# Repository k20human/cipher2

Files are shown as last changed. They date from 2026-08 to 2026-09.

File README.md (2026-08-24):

# cyberdeck

A handheld cyberdeck built around an Android phone: a lit pushbutton wakes its
screen, a rotary encoder sets the volume, a trackball moves a cursor, and the
phone's home screen is replaced by **CIPHER-2**, a landscape HUD served by the
phone to itself.

Three subsystems, each in its own directory, each with its own README.

```
                    USB HID (Power, volume, mute, mouse)
        ┌──────────────────────────────────────────────────┐
        │                                                  ▼
  ┌───────────┐                                    ┌───────────────┐
  │  Arduino  │                                    │    Android    │
  │  32U4     │◄───────────────────────────────────│    phone      │
  └───────────┘   USB serial "S<0|1> B<0..100>"    └───────────────┘
     button                (screen, battery)          │         ▲
     encoder                                          │ HTTP    │
     trackball                                        ▼ on 127.0.0.1
     button LED                                    ┌───────────────┐
                                                   │  CIPHER-2 PWA │
                                                   │  + Python API │
                                                   └───────────────┘
```

The board and the phone talk over one USB cable, in both directions at once but
for unrelated purposes:

- **Board → phone**, as a USB HID device: the Power key wakes and sleeps the
  screen, the volume and mute keys follow the encoder, and mouse reports follow
  the trackball. To the phone this is indistinguishable from its own buttons.
- **Phone → board**, as a USB serial device: the companion app reports screen
  state and battery level, one line every 5 seconds, so the button's LED can
  show them. Silence is information too — 15 s without a line and the LED starts
  blinking.

The interface never touches the network. Both the file server and the status
API listen on `127.0.0.1` only, and the page holds no language model and makes
no outbound request.

## Subsystems

| Directory | What it is | Read |
|---|---|---|
| `arduino/` | The `screen_wake` sketch: wake button, EC11 encoder, PIM447 trackball, button LED driven by what the phone reports. Host-side test suites in `arduino/test/`. | [arduino/README.md](arduino/README.md) |
| `android/` | `cyberdeck-reporter`, the companion app: watches the screen and the battery, writes them to the serial port, restarts at boot. | [android/README.md](android/README.md) |
| `gui/` | `CIPHER-2`, the deck's home screen: a PWA served from the phone by a small Python server that also exposes `GET /api/status`. | [gui/README.md](gui/README.md) |
| `pcb/` | `cipher2-panel`, the hub board: a Pro Micro on sockets, four connectors, and the cables to the controls. Generated from a netlist, not drawn. | [pcb/README.md](pcb/README.md) |

## Hardware

Developed and tested on an Arduino Leonardo driving an Android phone over USB
OTG. The board must have native USB — an Uno or a Nano cannot work — and the
alternatives are listed in [arduino/README.md](arduino/README.md#boards). The
phone side needs Termux and Termux:API, both from F-Droid.

The controls started out on flying wires and now have a board of their own:
`pcb/` holds a 100 × 42 mm two-layer hub that takes the Pro Micro on sockets
and gives the button, the encoder and the trackball a connector each — they
are mounted in the enclosure and reach it on cable. It is generated from a
netlist rather than drawn, and a test reads `screen_wake.ino` itself to check
the two agree — see [pcb/README.md](pcb/README.md).

## Quick start

Each subsystem stands on its own; none of them needs the other two to be
verified.

```sh
# Arduino — host test suites, no board required
make -C arduino/test test

# Arduino — build and upload
arduino-cli compile --fqbn arduino:avr:leonardo arduino/screen_wake
arduino-cli upload  --fqbn arduino:avr:leonardo -p /dev/ttyACM0 arduino/screen_wake

# GUI — test suite, no phone required (needs node and python3)
node --test "gui/test/**/*.js"

# GUI — serve locally
gui/serve.sh

# Android — unit tests (needs JDK 21 and the Android SDK)
cd android && ./gradlew test

# PCB — tests, then the fabrication package (needs KiCad 9)
make -C pcb test
make -C pcb fab
```

The Arduino sketch can be exercised without the phone: `arduino/tools/inject.py`
replays exactly the lines the Android app would send, including the silence that
puts the LED into its fault blink.

## Licence

MIT — see [LICENSE](LICENSE).

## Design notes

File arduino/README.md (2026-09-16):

# screen_wake

An illuminated pushbutton that turns an Android phone's screen on (and off), a
rotary encoder that sets its volume, and a trackball that moves a cursor on it.

The Arduino announces itself to the phone as a USB HID device. On the *consumer
control* interface it sends the Power, Volume +/- and Mute keys, which Android
translates into `KEY_POWER`, `KEY_VOLUMEUP`, `KEY_VOLUMEDOWN` and `KEY_MUTE`:
the effect is identical to that of the phone's own physical buttons. As a mouse,
it moves the pointer and clicks.

## Hardware

| Part | Detail |
|---|---|
| Board | ATmega32U4 — see *Boards* below |
| Button | Momentary pushbutton with a built-in LED, 4 wires, 3-6 V LED |
| Encoder | Bare EC11 — 3 pins for the quadrature, 2 for the switch |
| Trackball | Pimoroni PIM447 — I²C, with click and RGBW LED on the bus |
| Link | Android phone → OTG → unpowered USB hub → Arduino |

### Boards

Developed and tested on an **Arduino Leonardo** (`2341:8036`).

The board must have **native USB**, and the sketch's HID library (`HID-Project`
by NicoHood) targets AVR. That leaves the ATmega32U4 family, all
interchangeable here:

| Board | Note |
|---|---|
| Arduino Leonardo | The reference for this project |
| Arduino Micro | Same chip, smaller footprint |
| Pro Micro and clones | Cheapest option; check the 5 V variant, not the 3.3 V/8 MHz one |
| Adafruit ItsyBitsy 32u4, LilyPad USB | Same chip, different form factors |

An **Uno or a Nano cannot work**, whatever the wiring: their USB goes through a
CH340 or FT232 serial bridge, so they are physically unable to present
themselves as a keyboard. No sketch can work around that.

Native-USB boards that are *not* AVR — SAMD (Zero, MKR), RP2040, ESP32-S2 — do
have the USB capability but not `HID-Project`. Moving to one is a port of the
HID layer, not a change of `--fqbn`.

## Wiring

| Pin | Use |
|---|---|
| **D2** | Trackball — SDA, I²C bus |
| **D3** | Trackball — SCL, I²C bus |
| **D4** | Encoder switch (mute) |
| **D5** | Wake button |
| **D7** | Encoder, signal A |
| **D8** | Encoder, signal B |
| **D9** | Button LED, through a **150 Ω** resistor |

Every return goes to **GND**: the button's second contact, the LED cathode, the
encoder's middle pin, its switch's second contact, the trackball's ground. The
trackball also takes **5 V**.

**D2 and D3 are the ATmega32U4's only hardware I²C lines.** The trackball module
occupies them, and exposes its click *and* its four LEDs there — two pins for
both functions. That, and only that, is why the wake button moved from D2 to D5.

D7 and D8 for the encoder are not arbitrary either: once D2 and D3 are taken,
they are the last two pins able to raise an interrupt — D7 through an external
interrupt, D8 through a pin-change interrupt. The firmware polls the pins in a
loop rather than using interrupts; should detents ever be missed, the switch
could be made without touching a single wire.

No input needs a resistor: `INPUT_PULLUP` enables the microcontroller's internal
pull-up, which holds the pin at 5 V when idle. Acting on the control ties the
pin to ground, and the firmware detects that fall to 0 V.

### EC11 rotary encoder

Three pins on one side — the quadrature — and two on the other — the switch. The
**middle** one of the three is the common.

| Pin | To |
|---|---|
| 3-pin side, outer | **D7** |
| 3-pin side, **middle** | **GND** |
| 3-pin side, other outer | **D8** |
| 2-pin side, either | **D4** |
| 2-pin side, the other | **GND** |

**If the rotation comes out backwards**, swap the D7 and D8 wires. That is the
encoder's only wiring hazard, and it is harmless.

The 150 Ω resistor is a safety net. An LED sold as "3-6 V" almost always carries
its own, but in the worst case (no internal resistor, a red LED at 2 V) it caps
the current at 20 mA — the recommended limit for an ATmega32U4 pin.

### Pimoroni PIM447 trackball

An I²C module: the ball moves a cursor on the phone, its contact gives both
mouse buttons, and its RGBW LED shows the battery level.

**The module has a single contact**, and three gestures depend on it.
**Movement** is what tells them apart.

| What you do | What happens |
|---|---|
| You move the ball before `RIGHT_CLICK_MS` | The left button goes down → **drag**, until release |
| You do not move until the threshold | **Right click**, sent at once, finger still down |
| You release before the threshold without moving | **Left click** |

The left click can only fire on release: as long as the finger is down and the
threshold is not reached, nothing distinguishes a short press from a long press
in progress. The right click, on the other hand, fires **as the threshold is
crossed**, the way a touch interface behaves.

**You have to start moving within the delay** to get a drag. Press, wait, then
move gives a right click followed by an ordinary pointer move. That is the price
of fitting three gestures onto one contact.

`DRAG_THRESHOLD` sets the distance to travel before a hold becomes a drag. A
ball is sensitive and a resting finger nudges it: too low, and your right clicks
turn into accidental drags.

| Module pin | To |
|---|---|
| SDA | **D2** |
| SCL | **D3** |
| 5V (or 3V3) | **5V** |
| GND | **GND** |

The module is rated for 3.3 V **and** 5 V: it connects straight to the board, no
level shifter. An onboard microcontroller reads the click and drives the four
LEDs, exposing everything on the bus — **so the trackball costs no pin beyond
the two of the I²C bus**.

The bus runs at 100 kHz, `Wire`'s default. Do not speed it up: the manufacturer
rates the module at 250 kHz maximum.

**The module's orientation is baked into `decodeFrame`.** It sits a quarter turn
round in this deck — its own "right" points at the bottom of the panel — so the
axes are swapped once, where the module's language stops and the pointer's
begins. Mount yours differently and the pointer will travel at an angle to the
ball; the fix is those two lines in `trackball.h` and nothing else. The symptom
is unmistakable: push the ball up and the cursor goes sideways.

**What its LED says**

| State | Colour |
|---|---|
| Battery ≥ `BATT_GREEN_PCT` | green |
| Between the two thresholds | amber, by linear fade |
| Battery ≤ `BATT_RED_PCT` | red |
| Screen off | same hue, heavily dimmed |
| App silent **or** USB link down | **off** |

Going dark wins over dimming. When the app falls silent, the percentage the
board holds is minutes old: this build never asserts what it can no longer
answer for, and the same rule silences the button LED's battery alert.

**Without the module**, the identification probe fails at startup and the
trackball is never polled. Everything else — button, encoder, LED, serial link —
works exactly the same. That absence is a test case in its own right, not a
degraded mode.

**`POINTER_GAIN` is the one setting to make on the bench.** It multiplies the
ball's raw displacement. Too low and the cursor crawls; too high and it jumps.
The displacement is clamped to ±127 per report regardless, a bound imposed by
the mouse API.

### Identifying the button's 4 wires with a multimeter

Multimeter on **continuity** (the 🔊 symbol, which makes the meter beep when the
two probes are electrically joined):

1. Test the wires pair by pair **without pressing** the button. None should
   beep.
2. Press the button and test again. The pair that beeps is the **contact**.
   Those two wires go to D5 and GND, either way round.
3. The two remaining wires are the **LED**. Switch the meter to **diode** mode
   (the ▷| symbol) and test them both ways: the direction in which the LED glows
   faintly gives the polarity. The red probe is then on the anode (+, to D9), the
   black one on the cathode (−, to GND).

If step 3 gives nothing, the meter's test voltage is too low for the LED. Power
it carefully instead through a 330 Ω resistor from the board's 5 V, trying both
directions: at that value there is no risk.

## Building and uploading

```sh
arduino-cli compile --fqbn arduino:avr:leonardo screen_wake
arduino-cli upload  --fqbn arduino:avr:leonardo -p /dev/ttyACM0 screen_wake
```

`/dev/ttyACM0` belongs to the `dialout` group. To upload without `sudo`:

```sh
sudo usermod -aG dialout $USER    # then log out and back in
```

Dependencies: the `arduino:avr` core and the `HID-Project` library (NicoHood).

### If the upload fails

```
Error: butterfly_recv(pgm, &c, 1) failed
Error: initialization failed  (rc = -1)
```

An **intermittent** failure, seen once and gone on the second attempt with no
change at all. Re-running the command is usually enough.

The mechanism: to upload, `arduino-cli` opens the port at 1200 baud, which
restarts the board into its Caterina bootloader. That bootloader re-enumerates
as `idProduct=0036` and waits only **8 seconds** before handing back to the
sketch. The error above means avrdude opened the port but received nothing
during that window.

Prime suspect, unconfirmed: ModemManager is running and udev marks the port
`ID_MM_CANDIDATE=1`. Every time the bootloader appears, ModemManager may open it
to send AT commands, which garbles the AVR109 protocol. It is a race, hence the
intermittence. To rule it out for good:

```sh
sudo tee /etc/udev/rules.d/99-arduino-no-modemmanager.rules >/dev/null <<'EOF'
SUBSYSTEM=="usb", ATTR{idVendor}=="2341", ENV{ID_MM_DEVICE_IGNORE}="1"
EOF
sudo udevadm control --reload-rules
```

To watch the sequence live (membership of `adm` is enough, root is not needed):

```sh
journalctl -k --since "5 min ago" | grep -iE "usb|cdc_acm"
```

### Checking that the firmware is running

Without pressing anything, you can confirm the board really exposes the Power
key. The kernel parses the HID descriptor and publishes the codes the device
declares it can emit:

```sh
grep -A6 "Arduino" /proc/bus/input/devices
```

The current firmware exposes **two** devices: a generic entry — the Power,
volume and mute keys — and a `Mouse` entry, added for the trackball.

**The distinguishing criterion changed when the trackball arrived.** Seeing
`Mouse` no longer signals anything wrong: it is now expected. Seeing `Keyboard`
**as well**, on the other hand, betrays the stock factory firmware, which
exposed mouse *and* keyboard while never exposing a single media key. So the
call goes:

| What you see | What is running |
|---|---|
| A generic entry **and** `Mouse` | the current firmware |
| `Mouse` **and** `Keyboard` | the stock factory firmware — the upload did not take |
| A generic entry alone | a firmware predating the trackball |

The check that depends on none of these subtleties remains the best one: the
kernel publishes the codes the device declares it can emit, and `KEY_POWER`
(code 116) must be among them.

## What the LED says

Since the sketch reads the lines sent by the Android app (`led_state.h`,
function `ledLevel()`), the LED no longer reflects the state of the USB bus but
what the app reports. The order below is a priority order, not a list of
independent states: each row masks all the ones that follow.

| Priority | Condition | LED | What it means |
|---|---|---|---|
| 1 | Button or wheel press | Off, 120 ms | The key has just gone out (confirmation) |
| 2 | USB link absent | Off | OTG has dropped, or the rig has lost power |
| 3 | Android app silent | Blinks at 4 Hz | No line received for 15 s, or ever |
| 4 | Low battery reported | Two sharp flashes, every 5 s | Below 15 %, until back above 20 % (hysteresis) |
| 5a | Screen reported on | Steady glow | — |
| 5b | Screen reported off | Slow breathing, ~4 s | — |

The breathing does not peak exactly at the steady glow's level: integer
truncation of the squared triangular ramp (`breatheLevel()` in `led_state.h`)
caps the real peak at 23 when `LED_AWAKE`/`BREATHE_CEIL` are 24 — one PWM step,
invisible to the eye, and never more than that. The more active the screen, the
brighter and steadier the light.

The battery alert (priority 4) overlays state 5 but never a higher state: it
stays silent while the app is silent (priority 3), because a reading that can no
longer be guaranteed fresh must assert nothing about the battery.

Press confirmation is a **blackout** rather than a flash, because a dark gap is
noticeable from any state — including at the top of the breathing cycle or
mid-battery-flash, where a flash would go unnoticed.

Both buttons trigger it — the wake button and the wheel's click — because it
means "a key has just gone out", not "the screen has toggled". **Volume steps
are excluded**: a fast rotation would strobe the LED, and the confirmation would
become background noise rather than a signal.

### The board's TX/RX LEDs are off on purpose

Not through a fault. The Arduino core blinks them on every USB packet; with the
app reporting several times a second, that gives a permanent flicker nobody
reads. `silenceUsbLeds()` switches both pins back to inputs at startup, which
cuts the current through the LEDs without touching anything else.

It is the **direction register** that is changed, not the output: the core keeps
writing the port bits from its USB interrupt, and a pin set as an input ignores
them. It arms them as outputs only once, in `USBDevice.attach()`, which runs
before `setup()` — hence the window to undo its work.

Removing the call in `setup()` is enough to get them back. The board's "L" LED
(pin 13) is not affected.

### Where this information comes from

No longer the USB bus. This section used to describe a correlation between the
bus's suspend state (`USBDevice.isSuspended()`) and the phone's screen —
approximate and not guaranteed. The source is now explicit: the Android app
(`ReporterService`) watches the screen itself (`ACTION_SCREEN_ON` /
`ACTION_SCREEN_OFF` broadcasts) and the battery (`BatteryManager`), and reports
the real state line by line over that same serial port, every 5 s or immediately
on each screen toggle. The line format, the exact cadence and the reasoning
behind each choice are documented in `android/README.md` rather than duplicated
here.

The three functions below are still used in `screen_wake.ino`, but for a
narrower role than before: none of them serves to guess the screen state any
more, since the app now states it explicitly.

| Function | Current role |
|---|---|
| `USBDevice.configured()` | Feeds priority 2 of the table above (USB link present or not); also guards the keep-alive |
| `USBDevice.isSuspended()` | Decides whether `togglePhoneScreen()` must wake the bus before sending the key; same guard as above in the keep-alive |
| `USBDevice.wakeupHost()` | Wakes the bus, called only from `togglePhoneScreen()` |

`wakeupHost()` is only ever called on a real press, never automatically:
triggering it from the keep-alive would wake the phone every five minutes, night
included.

## Tuning points

Three files share the settings: the LED's vocabulary is in
`screen_wake/led_state.h`, the behaviour of the physical inputs in
`screen_wake/controls.h`, and the link's own timings at the top of
`screen_wake/screen_wake.ino`.

In `led_state.h`:

| Constant | Role |
|---|---|
| `LED_AWAKE` | Steady-glow intensity, 0-255. Also caps the breathing and serves as the blink's high level |
| `BREATHE_FLOOR` | Darkest point of the breathing cycle |
| `BREATHE_CEIL` | Nominal breathing ceiling, an alias of `LED_AWAKE` — never reached exactly (see above) |
| `BREATHE_MS` | Duration of one full breathing cycle |
| `BLINK_MS` | Half-period of the 4 Hz blink (app silent) |
| `BLACKOUT_MS` | Duration of the confirmation blackout |
| `APP_TIMEOUT_MS` | Time without a received line before declaring the app silent |
| `BATT_LOW_PCT` / `BATT_CLEAR_PCT` | Low/high thresholds of the battery hysteresis |
| `BATT_PERIOD_MS` | Period of the battery alert's two flashes |
| `BATT_FLASH_LEVEL` / `BATT_FLASH_MS` / `BATT_FLASH_GAP_MS` | Intensity, duration and spacing of each flash |
| `RX_BUF` | Maximum length of a serial line; beyond it, the line is truncated and rejected |

In `controls.h`:

| Constant | Role |
|---|---|
| `DEBOUNCE_MS` | Debounce, shared by both buttons; raise it if one press fires twice |
| `STEPS_PER_DETENT` | Quadrature transitions per detent. **If one detent changes the volume by two steps, set 2 instead of 4** |

In `trackball.h`:

| Constant | Role |
|---|---|
| `POINTER_GAIN` | Multiplier on the ball's displacement. **The only setting that needs the module in hand** |
| `RIGHT_CLICK_MS` | Press duration beyond which the click becomes a right click. Raise it if a hesitant press fires one unintentionally |
| `DRAG_THRESHOLD` | Distance to travel, in raw steps summed over both axes, for a hold to become a drag. Raise it if a resting finger starts accidental drags |
| `POINTER_MAX` | `127`, the bound imposed by `Mouse.move`; do not raise |
| `LED_FULL` | RGBW intensity with the screen on, capped low out of power caution |
| `LED_DIMMED` | RGBW intensity with the screen off |
| `BATT_GREEN_PCT` / `BATT_RED_PCT` | Bounds of the green → red gradient |

In `screen_wake.ino`:

| Constant | Role |
|---|---|
| `KEY_HOLD_MS` | Simulated press duration; stay below 500 ms |
| `RESUME_MS` | Delay after `USBDevice.wakeupHost()` before sending the key, time for the bus to settle |
| `KEEPALIVE_MS` | Interval of the empty HID report (see below) |

`STEPS_PER_DETENT` is the rig's one hardware unknown. Most EC11s emit four
transitions between two detents, some emit two. One turn of the wheel on the
bench settles it in ten seconds.

Volume steps deliberately escape `KEY_HOLD_MS`: holding each key for 60 ms would
cap a rotation at sixteen steps per second, and the firmware would spend that
time in `delay()` missing encoder transitions.

The whole breathing range fits in 22 PWM steps between `BREATHE_FLOOR` and
`LED_AWAKE`. If it looks jerky at the bottom, raise `LED_AWAKE` to give it more
amplitude — at the cost of power draw.

## Checking from a host machine, without the phone

Two tools exercise the firmware without unrolling the whole hardware protocol.

### Host tests: `make -C test test`

```sh
make -C test test
```

Compiles and runs **two** suites with `g++` (`-std=c++17 -Wall -Wextra
-Werror`, see `test/Makefile`), which share the `test/check.h` assertion
harness:

| Suite | Covers |
|---|---|
| `test_led_state.cpp` ← `led_state.h` | LED priorities, battery hysteresis, serial line format |
| `test_controls.cpp` ← `controls.h` | quadrature decoding, detent counting, debounce of both buttons |

Neither touches hardware: pin mapping, PWM, USB enumeration and HID behaviour
can only be verified with the board in hand.

The controls suite was validated by mutation: altering any one of the sixteen
entries in the quadrature table, the detent divider or the debounce window makes
at least one assertion fail. A test that passes just as well with the code as
without it proves nothing, and that table is exactly the kind of place where you
notice too late.

### Replaying the app's lines: `tools/inject.py`

```sh
tools/inject.py 1 87        # one line, screen on, battery 87 %
tools/inject.py --hold 0 14 # the same line every 5 s, until Ctrl-C
tools/inject.py --silent    # opens the port and says nothing
```

Sends to `/dev/ttyACM0` (`--port` to change) exactly the lines `ReporterService`
would send — see `android/README.md` for the real format and cadence — with no
need for the phone or the app. `--silent` reproduces an app killed by the OEM's
power manager: the LED must start blinking at 4 Hz after 15 s, as in the table
above. Requires `pyserial` (`pip install pyserial`) and access to the port (see
the `dialout` note above).

## Known limitations

**Some OEM skins drop OTG after ~10 minutes of inactivity** — measured on MIUI.
The sketch sends an all-zero HID report every 5 minutes: real USB traffic, no
key pressed. How well that counter-measure holds up has not been validated in
the field. If the link drops anyway, look for an OTG option in the phone's
settings, or go back to a powered hub.

**Do not test the button while the Arduino is plugged into a computer.** Once
the sketch is uploaded, the board is an HID device to *any* host: a press will
send the Power key to the computer and put it to sleep or shut it down. Unplug
from the computer before wiring the button.

## If the phone ignores the key

Two fallbacks, to try in this order if `Consumer.press(CONSUMER_POWER)` is not
enough:

1. `System.write(SYSTEM_WAKE_UP)` — HID *Generic Desktop* usage 0x83,
   translated into `KEY_WAKEUP`. Turns the screen on but never off. Needs
   `System.begin()` in `setup()`.
2. `SingleConsumer` instead of `Consumer` — same key, but exposed on a dedicated
   HID interface rather than inside the composite descriptor. Some hosts cope
   better with it.

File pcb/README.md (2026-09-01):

# cipher2-panel

La carte de raccordement du deck : elle porte le Pro Micro sur embases, les
quatre connecteurs des commandes, et rien d'autre.

**100 × 42 mm**, deux couches, 1,6 mm, cuivre 35 µm. Elle se loge dans la bande
libre du boîtier, sous le hub USB, et n'est jamais visible.

## Ce que la carte n'est pas

Elle a d'abord été conçue comme une **façade** portant le bouton, l'encodeur et
le trackball soudés dessus. Le boîtier a tranché autrement : les trois commandes
sont montées dans le plastique, loin les unes des autres, et rejoignent la carte
par câble.

Ce qui reste est un concentrateur. Le circuit occupe un quart de la surface ; le
reste appartient au wordmark.

## La carte est générée, pas dessinée

Un seul fichier, `tools/netlist.py`, énumère les liaisons. Le schéma et la
carte en sont produits par script. Deux générateurs ne peuvent pas diverger
d'une source unique.

**Conséquence pratique : on ne modifie jamais `cipher2-panel.kicad_pcb`.** On
modifie `netlist.py` pour une liaison, `PLACEMENT` pour une position, `ROUTES`
ou `ESCAPES` pour une piste, puis on régénère. Une retouche faite dans
l'interface graphique est perdue à la prochaine exécution, sans avertissement.

```sh
make -C pcb test        # les 58 tests, sans matériel ni KiCad ouvert
make -C pcb board       # schéma + carte + DRC
make -C pcb fab         # tout cela, puis les fichiers de fabrication
make -C pcb render      # vues 3D et couches, dans render/
```

## Brochage

Contractuel : le firmware ne change pas pour s'adapter à la carte.

| Broche | Rôle | Sur la carte |
|---|---|---|
| **D2** | Trackball — SDA | `J1.2` |
| **D3** | Trackball — SCL | `J1.3` |
| **D4** | Contact de l'encodeur | `J3.4` |
| **D5** | Bouton d'éveil | `J4.1` |
| **D7** | Encodeur, voie A | `J3.1` |
| **D8** | Encodeur, voie B | `J3.3` |
| **D9** | LED du bouton, via R1 | `R1` → `J4.3` |

`test/test_pinout.py` lit `arduino/screen_wake/screen_wake.ino` lui-même et
vérifie cette correspondance. Une broche renumérotée dans le croquis fait
échouer les tests au lieu d'arriver sous forme de carte morte.

## Les quatre connecteurs

Toutes les broches sont sérigraphiées sur la carte. Les câbles sont des
liaisons Dupont femelle-femelle, **sans détrompeur** : rien n'empêche une
inversion, et sur le trackball une inversion met 5 V sur la masse du module.
C'est la sérigraphie, et elle seule, qui vous protège.

### `J1` — trackball, 5 points

`+5V · SDA · SCL · INT · GND`, dans l'ordre du connecteur du PIM447. Câble
droit, broche 1 sur broche 1.

**Garder ce câble sous 30 cm.** Le bus I²C tolère mal la capacité, et c'est la
raison pour laquelle la carte est calée à gauche du boîtier, près du trackball,
plutôt qu'à droite près du hub. L'USB, lui, tolère cinq mètres.

### `J3` — encodeur, 5 points

`A · GND · B · SW · GND`. L'EC11 a cinq bornes en deux groupes :

| Broche de la carte | Borne de l'encodeur |
|---|---|
| `A` | une extérieure du groupe de trois |
| `GND` | **celle du milieu du groupe de trois** |
| `B` | l'autre extérieure |
| `SW` | une des deux du groupe de deux |
| `GND` | l'autre |

Les noms de la fiche technique sont `A`, `C`, `B`, `S1`, `S2` ; la carte
affiche ce que chaque broche *est*, parce qu'on la câble un sachet de fils à
la main et pas la fiche technique sous les yeux.

**Une seule chose doit être juste : le milieu du groupe de trois va sur
`GND`.** A et B sont interchangeables — les inverser retourne le sens de
rotation, ce qui se corrige en échangeant deux fils. S1 et S2 n'ont pas de sens.

### `J4` — bouton d'éveil, 4 points

`SW · GND · LED+ · GND`. Le contact n'a pas de polarité ; la LED en a une, et
c'est le seul piège de ce connecteur.

### `J2` — broches libres, 6 points

`D1 · D0 · D6 · D10 · +5V · GND`. D0 et D1 sont la liaison série matérielle,
celle qu'on utilise pour déboguer. Les deux rails permettent de mesurer sans
démonter le module.

Il n'y a **pas de broche de reset** : la carte vit dans un boîtier fermé, et
débrancher l'USB fait le même travail depuis l'extérieur.

## Le Pro Micro est monté à l'envers

Ses barrettes ont été soudées broches vers le haut. Pour l'enficher dans les
embases, il faut le retourner — composants vers la carte — et cela échange ses
deux rangées de broches. **L'empreinte les rééchange**, ce qui rend le montage
correct sans dessouder 24 broches.

Le coût est permanent et il faut le connaître : **un Pro Micro de remplacement
soudé de la façon habituelle ne rentrera pas.** Il faudra soit refaire ses
barrettes broches vers le bas, soit inverser l'empreinte dans
`tools/build_footprints.py`.

La sérigraphie porte `PRO MICRO - COMPONENTS DOWN`. Monté à l'endroit, le
module met **5 V sur la masse du trackball** et le détruit.

**Les embases et les barrettes ne figurent dans aucune nomenclature** : elles
accouplent `U1`, elles ne sont pas des composants du schéma, et `fab/bom.csv`
est généré depuis ce schéma. Leurs références, et la barrette à ne surtout pas
acheter, sont dans [`lib/PARTS.md`](lib/PARTS.md).

Le connecteur USB déborde du bord droit. Une fiche coudée occupe 16 mm au-delà
du bord ; une fiche droite en demande une cinquantaine avec sa courbure.
**Un coudé a un sens** : retourner le module retourne son coude, et en
micro-USB — non réversible — le coude peut venir buter sur la carte.

## Ce qui est dessiné mais non monté

| Repère | Rôle | Pourquoi il est là |
|---|---|---|
| `R2`, `R3` | Rappels I²C 4,7 kΩ | Le PIM447 embarque les siens. Mais le bus sort désormais de la carte sur un câble, et sa capacité augmente : ces deux emplacements ont plus de chances de servir qu'à l'époque où le module était à 10 mm |
| `SJ1` | Pont à souder, ouvert | Relie l'interruption du trackball à **D14**, qui porte `PCINT3`. Le firmware interroge le module en boucle et n'en a pas besoin ; le fermer réserve D14 au trackball |

`R2` et `R3` figurent dans `fab/bom-full.csv` marquées `DNP` — ce sont des
pièces achetables qu'on choisit de ne pas monter. `SJ1` n'y figure pas : un
pont à souder est du cuivre, pas une pièce qu'on commande.

**Seuls `R1` et `C1` sont à souder.**

## Le wordmark

**Sérigraphie blanche sur vernis noir**, 61 × 18 mm — un tiers de la surface
de la carte.

Il a d'abord été une ouverture dans le vernis, les lettres étant le plan de
masse doré apparaissant dessous. C'était une erreur : la couleur du logo
devenait otage de la finition cuivre — gris en HASL, or seulement en ENIG, que
PCBWay facture 35 $. En sérigraphie, les lettres sont blanches quelle que soit
la finition, et **le choix de finition redevient purement fonctionnel**.

### Deux polices, et pourquoi

Le nom est en **Cyberway Riders**. Le chiffre est en **DejaVu Sans Mono**.

Cyberway Riders dessine son `2` avec un sommet plat et une diagonale droite :
à toute taille il se lit `Z`, et la carte annonçait CIPHER-Z. Le chiffre vient
donc d'ailleurs — mais pas de n'importe où : DejaVu Sans Mono est la police de
l'interface, celle que `--font-mono` nomme dans `gui/src/styles/theme.css`. La
police d'affichage porte le nom, celle de l'interface porte le numéro.

Mélanger deux fontes impose de les **accorder** : même hauteur de capitale,
même ligne de base, écart réglé. Rien de cela ne se calcule depuis la taille
nominale, parce qu'une fonte déborde couramment de ses métriques déclarées.
`align_wordmark()` mesure l'encre rendue et corrige. Trois tests gardent ce
calage.

### La cote qui compte : l'encre, pas la boîte

`test_wordmark.py` mesure l'étendue réelle des glyphes avec
`GetEffectiveTextShape()`, jamais `GetBoundingBox()`.

**Cyberway Riders déborde de ses propres métriques de 0,24 mm.** À la première
tentative, le haut des lettres arrivait à 0,26 mm du bord de carte — hors du
plan de masse — et tous les contrôles étaient au vert.

### Changer de police

Deux lignes dans `tools/build_board.py` :

```python
WORDMARK_FONT = "Cyberway Riders"
DIGIT_FONT = "DejaVu Sans Mono"
```

Le nom doit être la famille exacte vue par fontconfig
(`fc-query -f '%{family}\n' fichier.otf`). La police n'a besoin d'être
installée **que sur la machine qui exporte** : les Gerbers sortent avec les
lettres déjà converties en formes.

### Le seul avertissement DRC accepté

Cyberway Riders a des terminaisons **pointues**, et une pointe passe sous
l'épaisseur minimale de trait par construction. Augmenter l'épaisseur du texte
n'y change rien : KiCad mesure le contour brut de la police. Sur la carte, les
pointes s'impriment légèrement arrondies.

L'exception est déclarée dans `tools/check_drc.py` avec son argument, et
`test_drc_rules.py` interdit à la liste de s'allonger. Elle n'est pas
désactivée dans le fichier de projet : **KiCad y réécrit tout le bloc
`rule_severities` à chaque exécution.**

## Vérification

```
screen_wake.ino ──test──> netlist.py ──generateur──> schema ──ERC──> 0
                              │                         │
                              │                    parite DRC
                              └──generateur──> carte ──────┘
```

| Maillon | Ce qu'il prouve |
|---|---|
| `test_pinout.py` | La carte suit le firmware réel, pas une transcription |
| `test_symbols.py` | Chaque numéro de broche correspond au nom de pastille de son empreinte — **la seule erreur que l'ERC ne voit pas** |
| `test_footprints.py` | L'empreinte du Pro Micro a les cotes du module réel |
| `test_placement.py` | Rien ne déborde, rien ne se chevauche, l'USB sort bien du bord droit |
| `test_netlist_roundtrip.py` | KiCad lit le schéma comme nous l'avons voulu |
| `test_wordmark.py` | Les deux moitiés du logo partagent ligne de base et hauteur |
| `test_drc_rules.py` | La liste des avertissements tolérés ne s'allonge pas en silence |
| `TestBoardSize` | Le contour, la constante du générateur et la cote citée dans ce README disent la même chose — ils ont divergé une fois |
| ERC | Schéma cohérent — 0 violation |
| `check_drc.py` | 0 erreur, 0 différence de parité, 0 non-connecté |

État : **58 tests**, 61 segments de piste, 21 vias, 16 nets, 46 liaisons,
8 broches déclarées non connectées.

### Le routage en couloirs

Neuf signaux quittent la rangée basse du Pro Micro et traversent la carte vers
l'ouest. Chacun prend une **voie horizontale au dos**, puis un via, puis
descend vers son connecteur **en face avant**. Voies et descentes sur deux
couches différentes : une descente peut franchir n'importe quelle voie sans la
toucher, et c'est toute la raison du via.

L'ordre des voies n'est pas arbitraire. La pastille la plus à l'ouest prend la
voie la plus proche de la rangée, et les voies montent à mesure que les
pastilles vont vers l'est. Chaque sortie ne franchit alors que des voies dont
le parcours s'arrête plus à l'ouest qu'elle. **Dans l'ordre inverse, les neuf
se croisent toutes.**

## Les fichiers sont équivalents d'une génération à l'autre, pas identiques

Régénérer produit des Gerbers qui ne sont **pas** octet pour octet les mêmes.
Mesuré sur deux exécutions consécutives :

| Couche | Écart |
|---|---|
| `F_Cu`, `F_Mask`, les deux sérigraphies, `B_Mask`, `Edge_Cuts` | géométriquement identiques |
| `.drl` | identique, hors horodatage |
| `B_Cu` | **un sommet sur 3 265** dans le contour du plan de masse |

Deux causes, toutes deux dans KiCad. Les **ouvertures sont numérotées** dans
l'ordre où l'exportateur rencontre les empreintes, et cet ordre n'est pas
stable dans le `.kicad_pcb` : la même forme reçoit `D10` à une exécution et
`D12` à la suivante. Et le **remplisseur de zone** tessellise avec une
tolérance, d'où le sommet en trop.

Les deux cartes passent le DRC à `0/0/0` et se fabriquent à l'identique. Mais
la conséquence pratique est réelle :

**Ne régénérez pas entre la relecture et le téléversement.** Relisez le zip que
vous allez envoyer, et envoyez celui-là. Sinon vous téléversez un fichier
équivalent à celui que vous avez examiné, pas le même.

## Commander chez PCBWay

Une seule série, définitive. Le formulaire de devis affiche déjà les bonnes
valeurs pour la plupart des champs ; **quatre seulement sont à changer**.

| Champ | Valeur |
|---|---|
| Size (single) | **100 × 42 mm** |
| Quantity | **5** |
| Solder mask | **Black** |
| Remove product No. | **Specify a location** |
| *(déjà bons)* | Single pieces · 1 design · 2 Layers · FR-4 · TG 150-160 · 1,6 mm · 6/6 mil · 0,3 mm · Silkscreen White · UV printing None · Edge connector No · **HASL with lead** · Tenting vias · 1 oz Cu |

**HASL avec plomb est l'option de base, sans supplément.** Rien de visible n'en
dépend puisque le wordmark est en sérigraphie ; le sans-plomb coûte 13 $ et
l'ENIG 35 $ pour un résultat identique à l'œil. L'alliage plombé se soude même
mieux au fer. Sa seule contrepartie est l'absence de conformité RoHS, ce qui
compte pour vendre, pas pour construire un exemplaire.

**Cocher « Specify a location »** : la sérigraphie porte le repère `WayWayWay`
en bas à droite, la convention documentée de PCBWay pour désigner où poser leur
numéro de série. Sans cette case, ils ne cherchent pas le repère et le texte
`WayWayWay` s'imprime tel quel. Le supprimer coûterait 1,50 $.

Téléverser `fab/cipher2-panel-gerbers.zip`. Joindre en commentaire :

> Internal cutout: none. Standard 2-layer board.

Le visualiseur Gerber en ligne n'accepte **pas** les archives : lui donner les
fichiers décompressés de `fab/gerbers/`.

| Fichier | Contenu |
|---|---|
| `fab/cipher2-panel-gerbers.zip` | Ce qu'on envoie au fabricant |
| `fab/bom.csv` | Ce qu'on commande |
| `fab/bom-full.csv` | Tout, `DNP` compris |
| `fab/placement.csv` | Centroïdes, si vous prenez l'assemblage |
| `mech/*.dxf` | Contour et repères, pour le boîtier |
| `render/` | Vues 3D et couches, régénérables |

## Le contrôle à faire avant de brancher le trackball

**Dix secondes de multimètre, et c'est le seul geste qui attrape une erreur
d'orientation avant qu'elle ne coûte un module.**

Montez la carte, enfichez le Pro Micro, alimentez par l'USB — **et rien
d'autre**. Aucun câble sur `J1`, `J3` ni `J4`.

Multimètre en tension continue, pointe rouge sur `J1.1`, pointe noire sur
`J1.5` :

| Lecture | Signification |
|---|---|
| **+5 V** | L'orientation est bonne. Branchez le trackball. |
| **−5 V** | Les rails sont inversés. **Débranchez tout.** |
| **0 V** | Rien n'arrive. Vérifiez le module et le câble avant d'aller plus loin. |

Même relevé sur `J2.5` et `J2.6`, qui portent les mêmes rails et servent de
contre-épreuve.

Pourquoi ce contrôle existe : le Pro Micro est monté à l'envers, et l'empreinte
compense cette inversion. Si le module arrivait un jour avec ses barrettes
soudées dans l'autre sens — un remplacement, une réparation — la compensation
deviendrait l'erreur, et **5 V se retrouveraient sur la masse du trackball**.
Ni l'ERC, ni le DRC, ni aucun test de ce dépôt ne peut voir cela : ils
décrivent la carte, pas le module qu'on y enfiche.

Le trackball meurt en silence et sans fumée. Le multimètre coûte moins cher.

## Points de vigilance au montage

| Point | Conséquence si c'est faux |
|---|---|
| **Sens du Pro Micro** — composants vers la carte, repère `D1`/`RAW` côté USB | 5 V sur la masse du trackball, module détruit |
| **Sens du connecteur trackball** — câble droit, broche 1 sur broche 1 | Idem |
| **Polarité de la LED du bouton** — `LED+` sérigraphié | La LED n'allume pas |
| **Milieu du groupe de trois de l'encodeur sur `GND`** | L'encodeur ne compte pas |
| **Ordre de soudure** — R1 et C1 avant les embases | Les 1206 deviennent difficiles d'accès |
| **Embases à contacts estampés**, jamais tulipe | Une broche carrée de 0,64 mm mesure 0,90 mm en diagonale et n'entre pas dans un contact tulipe |
| **Embases soudées avec le module en place** comme gabarit | Soudées à main levée, les deux brins dérivent et le module n'entre plus |
| **Pastilles de masse reprises plus chaud et plus longtemps** | Le plan de masse est en liaison pleine sur les deux faces : il pompe la chaleur et laisse un joint froid |
| **Broches arasées sous la carte** | Trois câbles USB passent dessous ; un bourrelet de soudure finit par les user |

## Sans le module trackball

La carte fonctionne. La sonde d'identification échoue au démarrage, le
trackball n'est jamais interrogé, et le bouton, l'encodeur, la LED et la
liaison série sont inchangés — exactement comme le décrit
[`arduino/README.md`](../arduino/README.md). Cette absence est un cas de test,
pas un mode dégradé.

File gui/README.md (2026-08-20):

# cyberdeck-gui

The cyberdeck's home screen, under the name **CIPHER-2**: title band, simulated
AI avatar with its journal, a system status column fed by real data, shortcuts,
settings, animated background. A web page installed on the phone's home screen,
served from the phone itself. Nothing leaves the device — both the status API and
the file server listen on `127.0.0.1` only.

A complete redesign of a first version that was portrait, single-column and
plainer.

## Layout

**Landscape only.** Portrait is abandoned: there is no fallback layout, and
`manifest.json` declares `"orientation": "landscape"` so the installed app forces
the orientation however the phone is held.

```
┌──────────────────────────────────────────────────────┐
│  [LOGO CIPHER-2]  ▮▮▮ 7H3 N37 15 ▮▮▮▮ V467 ▮▮ 1NF1 173 ▮▮  │  band
├────────────────────────────┬───────────────────────────┤
│                            │  system status            │
│      CIPHER-2 avatar       │  or shortcut grid         │
│      + journal             │  (one at a time)          │
│                            │  [prompt] toggles between │
│                            │  the two                  │
├────────────────────────────┴───────────────────────────┤
│  21:48  17/08/2026                      ////////////   │  footer
└──────────────────────────────────────────────────────┘
```

The band alternates barcodes and code groups across its whole width, and the
footer's ribbon is made of two overlapping rows of slanted bars — both taken from
a reference photo of a physical cyberdeck HUD (not part of this repository),
which is the authority on appearance. The barcode segments are real elements in
`index.html`: it is the alternation that makes the band read as an instrument's
header, and that cannot come from a single pseudo-element placed after the text.

Three bands in a grid (`#deck`, height fixed at `100svh` — never `min-height`,
without which nothing bounds the middle row). The band carries the logo and a
line of decorative, meaningless codes. The left band (two thirds of the width)
carries CIPHER-2's avatar and its journal. The right band (one third) is **a
screen, not a stack**: it shows either the system status or the shortcut grid,
never both — see *Settings* for `layout.rightView`. Below the readings, a rule
separates the closing verdict (`verdictLine`, in `journal.js`): "All systems
nominal, Operator." while all is well, but **it reports, it does not reassure**.
Any of the readings above can contradict it, worst first since only one sentence
is shown: link lost, critical battery, disk nearly full, memory saturated,
sustained processor load. A lost link comes before everything else — without it,
every other line is a memory rather than a measurement.

The final address (", Operator.") is appended once, to the sentence and not to
each phrasing: that is what makes it impossible to forget in a case added later,
and a test checks it across all nine states, including the ones that fail to
read. The thresholds are gathered at the top of `journal.js`, and the battery one
is shared with `stateLines` — the verdict and the left-hand journal are read side
by side, and a threshold written twice ends up diverging. The journal itself no
longer says "ALL SYSTEMS NOMINAL": two assertions about the same thing, one of
them unconditional, was one too many, and it is the unconditional one that went.

The footer carries the clock (always on one line, time and date side by side,
always 24 h) and the ribbon, which spans exactly the width of the right column:
the footer reuses the deck's column grid (`--deck-columns`) instead of redoing
the calculation, so the two can never diverge. Its background mixes 88 % of the
theme colour (not an opaque fill) to stay readable under the rain.

**Switching between status and shortcuts:**

| Gesture | Effect |
|---|---|
| `Enter` key (outside a text field) | Next view, cyclically |
| Tapping the prompt at the foot of the view (`[ENTRÉE] ACCÉDER AU DECK` / `[ÉCHAP] RETOUR`) | The same effect, without a keyboard |
| `Escape` key | Back to the default view (the status) |

The prompt is the only clickable element that changes view; the body of each view
(tiles, status lines) stays inert for that purpose, so a tap that launches a
shortcut never switches the screen by accident.

No dimension is tuned to a particular phone: text sizes derive from `vmin` (never
`vw`, which in landscape follows the width — the dimension that is not the
constraint), and the right band scrolls for itself rather than pushing the footer
off screen when the shortcut list grows.

## What each file does

| File | Role |
|---|---|
| `index.html` | DOM skeleton of the three bands, stylesheets, effects layer, settings button, mounting of `src/main.js`. |
| `manifest.json` | PWA manifest: `standalone` mode, `orientation: landscape`, icons. |
| `serve.sh` | One-line wrapper that launches `tools/serve.py`. |
| `sw.js` | Service worker: strict precache of everything the server serves, purges the old cache on activation, never caches itself. |
| `src/main.js` | Bootstrap: store, theme, ambience, effects, mounting of modules per band, keyboard view switching, service worker registration. |
| `src/core/schema.js` | Shape of the configuration, default values (including the four original shortcuts), field-by-field validation that never throws. |
| `src/core/store.js` | Persistence in local storage, subscriber notification, export/import, frozen exposed object. |
| `src/core/theme.js` | Palettes and hue rotation — only the ink rotates, never the background. |
| `src/core/registry.js` | Generic module registry: mount band (`containerFor`), order, view cycle (`nextInCycle`), mount/unmount. |
| `src/core/journal.js` | Boot phrases and status lines for CIPHER-2's journal. An array of sentences, no language model. |
| `src/core/telemetry.js` | Parsing of the `/api/status` response, age of a datum, staleness, formatting of the displayed lines. |
| `src/core/effects.js` | Translates the five "Effets" settings into CSS classes set on `<body>`. |
| `src/ambient/engine.js` | Render loop with a capped frame rate, suspended off screen; drives both the background and the canvas avatars. |
| `src/ambient/rain.js` | The code rain — the only effect entrusted to the background canvas. |
| `src/ai/registry.js` | Index of the twelve avatars, on the exact model of the module registry. |
| `src/ai/avatars/*.js` | One avatar per file — eight in SVG (`core`, `halo`, `halo-live`, `wave`, `wave-live`, `iris`, `lattice`, `lattice-live`), four in canvas (`nexus`, `nexus-pulse`, `vortex`, `cipher-core`) — see the table below. |
| `src/modules/cipher.js` | Left band module: mounts the chosen avatar, shows the journal below it. |
| `src/modules/clock.js` | Clock (always 24 h) and date, in the footer. |
| `src/modules/status.js` | Polls `/api/status` at a settable interval, shows the system status, handles the degraded mode. |
| `src/modules/shortcuts.js` | Shortcut grid, editor built into the panel, target normalisation. |
| `src/modules/logo.js` | Renders the logo in one of the four treatments. |
| `src/settings/panel.js` | Builds the panel from the declarations in `core-settings.js` and in each module; knows no module in particular. |
| `src/settings/core-settings.js` | Declarations of the cross-cutting settings: theme, ambience, effects, layout. |
| `src/settings/transfer.js` | The panel's "Système" section: copy/download/import/reset the configuration, storage warning. |
| `src/styles/theme.css` | Palette CSS variables (startup values, before the store is first read). |
| `src/styles/base.css` | Module styles: clock, shortcut grid, tiles, avatar, status lines, view prompt. |
| `src/styles/layout.css` | The three-band grid, sizing in `svh`/`vmin`. |
| `src/styles/panel.css` | Styles of the settings panel and the shortcut editor. |
| `src/styles/logo.css` | The four logo treatments. |
| `src/styles/avatars.css` | Styles and animations shared by the eight SVG avatars; sizing shared with the canvas avatars. |
| `src/styles/effects.css` | Implements the five surface effects on the `#overlay` layer and on `#deck`. |
| `tools/serve.py` | Development server: correct MIME types for a PWA, `GET /api/status` route. |
| `tools/status.py` | System probe: IP, battery, Wi-Fi, processor, memory, storage, uptime — each source isolated in its own guarded block. |
| `tools/make_icons.py` | Builds the PNG icons (`pip install pillow` required — the project's only tool that leaves the stdlib, a choice confined to this generator and never run on the phone). Re-run after a change; the PNGs are committed. |
| `icons/*.png` | Application icons (192, 512, 512 maskable), generated by `tools/make_icons.py`. |
| `tools/boot/` | Scripts run at device startup by Termux:Boot — see *Automatic startup*. |

## CIPHER-2: avatar and journal

An ordinary module (`src/modules/cipher.js`) occupies the left band. It draws
nothing itself: it picks an avatar from the registry according to the "Avatar"
setting, mounts it, and shows the journal below. Changing avatar remounts only
the avatar, never the whole module.

| id | Rendering | Description |
|---|---|---|
| `core` | SVG | Wireframe sphere and polyhedral heart in counter-rotation. |
| `halo` | SVG | Rings of short dashes, central sphere, halo — after Jarvis. |
| `halo-live` | SVG | The same, animated: fast rings, radar sweep, pings leaving the core. |
| `wave` | SVG | Oscilloscope: the wave contracts and swells, and rises/falls. No sideways scrolling. |
| `wave-live` | SVG | The same, pushed further: amplitudes in phase opposition, wider oscillation, level bars. |
| `iris` | SVG | A contracting iris, reticle and tick marks. |
| `lattice` | SVG | A node mesh lighting up in cascade, scanning bar. |
| `lattice-live` | SVG | The same, animated: signals run along the edges, brighter nodes, spinning hub. |
| `nexus` | Canvas | 440 points on a sphere, projected in perspective. |
| `nexus-pulse` | Canvas | The same, with a slow breathing of the sphere (~22 s cycle, 54 % measured amplitude). |
| `vortex` | Canvas | 620 particles on a turbulent ring, wire core. |
| `cipher-core` | Canvas | Code rain confined to a disc. |

`wave` lost the reference's sideways scrolling, in **both** versions, in favour
of vertical motion: the wave contracts and swells about its axis and rises and
falls, without ever moving anything sideways. The trace is therefore re-anchored
on the frame — ten arches of 18 units cover exactly x=10 to x=190, five whole
periods, where it used to overflow by 160 units to feed the scroll. The
`clipPath` moved from the viewBox to **the frame's own rectangle** (10,52 to
190,148): whatever the amplitude does, nothing is drawn outside the box — a
guarantee that arithmetic alone held only as long as nobody changed a number.
Measured over a full cycle: `wave` paints between 58.6 and 133.9, `wave-live`
between 61.3 and 140.6, for a frame running from 52 to 148.

`nexus-pulse` is `nexus` identically, with a breathing cycle as its only
addition: the radius traces a cosine over 660 frames, about 22 s at the 30 fps
cap. It **contracts** from its full size and returns to it, rather than growing
beyond — `nexus`'s 0.36 was chosen against the band, and exceeding that value
would push points out of the box on every breath.

Depth, not speed, is the lever on visibility. At a minimum radius of 0.72 the
breathing existed without being seen: 28 % of variation spread over half a minute
changes the radius by a fraction of a percent per second, below the threshold of
perception on a sphere of sparse points. At 0.45, the painted radius measured on
screen runs from 253 to 116 px — **54 % of amplitude** — and the cycle stays
slow.

The rotation of both Nexus avatars was halved (`frame / 280` and `frame / 600`
instead of 140 and 300): one revolution in about a minute on one axis, two on the
other. That is a drift rather than a rotation, which makes it bearable next to a
status column someone is trying to read.

The three `-live` variants exist because the originals are slow by design —
`halo`'s rings take 13 to 34 seconds for one turn — and slow enough reads as
still: measured over 1.7 s, the three moved only 1.25 %, 0.65 % and 0.54 % of
their pixels. They are added alongside the originals, not in their place, and
filed right after the one they are the counterpart of: the choice is between two
tempos of the same avatar, not among eleven unrelated avatars.

The SVG avatars animate only `transform`, `opacity` and `stroke-dashoffset`: the
first two are the compositor's business. The third is not, but it applies to a
dozen short paths and replaces the only other way of running a signal along an
edge — moving the geometry — which would cost a layout pass every frame. Nothing
here animates a property that triggers layout.

All the animations are carried by descendants of `.avatar__svg` or
`.avatar__stage`, so the `prefers-reduced-motion` rule at the bottom of
`avatars.css` reaches them with no extra line. Verified: 9, 17 and 23 active
animations under normal conditions for the three variants, zero under reduced
motion. The canvas avatars hitch onto the same ambience engine as the background
(`src/ambient/engine.js`), with their own frame-rate cap — measured at the left
band's real size on the reference phone (≈ 600 × 380) at between 0.15 and 0.58 ms
per frame depending on avatar and theme, so with headroom to spare even with the
animated background running at the same time.

The journal (under the avatar) shows a few `>`-prefixed lines: boot phrases on
opening, then lines drawn from the deck's real state (low battery, link lost).
**No language model, no network call**: an array of sentences and a selection
rule (`src/core/journal.js`). The "Journal" setting turns it off.

## Logo

Four treatments, all pure text and CSS — no image file:

| id | Treatment |
|---|---|
| `glitch` | Red and cyan fringing, halo, and the word sliced into laterally displaced bands (two bursts per 9 s cycle). |
| `plate` | Black text on a solid block, bevelled corners. |
| `frame` | Spaced lettering, double frame, glow. |
| `major` | Angular, fragmented lettering, after a separate reference image. |

`glitch`'s slicing relies on two copies of the word, superimposed on the original
and each cropped to a horizontal band. Each carries `background: var(--bg)`, and
that opacity is the whole trick: an opaque band that slides **covers** what it
crosses, so the slice reads as displaced rather than duplicated — a transparent
copy would only give a double exposure. `steps(1, end)` on both animations, so
that every keyframe is a hard cut: the default interpolation would slide the
bands smoothly, which is a different thing entirely, a fault having no
intermediate states. Both spend most of the cycle on a band of zero height,
because a permanent disturbance stops being a disturbance and becomes a texture.

The previous effect was an opacity drop at 97 % of a six-second cycle — one frame
every six seconds, indistinguishable from nothing.

The cadence is measured by driving the animation's clock frame by frame rather
than hoping a screenshot loop keeps up with real time: a screenshot costs far
more than the interval separating it from the next one, and a first measurement
made that way covered three cycles while believing it covered one. Over the 9 s
cycle, the cuts fall at 0.3-0.5 s, 1.0-1.2 s and 5.3-5.4 s: a double burst, four
seconds of calm, a lone cut, four seconds of calm. Grouped and not spread out —
evenly spaced faults sound like a metronome, grouped ones sound like a bad
connection.

## System status

A web page knows nothing of the local IP address, processor load, memory, storage
or Wi-Fi state; only the battery is sometimes exposed by the browser. That is why
`tools/serve.py` gains a `GET /api/status` route which returns:

```json
{
  "ts": 1755300000,
  "ip": "192.0.2.42",
  "battery": { "percent": 87, "charging": false, "temperature": 31.2 },
  "wifi": { "ssid": "…", "rssi": -47, "link_speed": 433 },
  "cpu": { "load": 0.34 },
  "memory": { "used_mb": 2841, "total_mb": 5734 },
  "storage": { "free_gb": 37.1, "total_gb": 58.0 },
  "uptime_s": 184922
}
```

`tools/status.py` queries each source in its own guarded block: a missing or
failing command sets its field to `null` without stopping the others from
answering. **Only `battery` and `wifi` depend on `termux-api`**
(`termux-battery-status`, `termux-wifi-connectioninfo`) — `ip`, `cpu`, `memory`,
`storage` and `uptime_s` read `/proc`, `ip -j addr`/`ifconfig` and
`shutil.disk_usage`, available with Termux alone.

**Uptime is computed, not read.** With `/proc/uptime` denied on Android, the
probe falls back to `/proc/self/stat`: a process can always read its own entry,
whose 22nd field is the instant it started, in ticks since boot. The server adds
its own lifetime to that and obtains the same number without ever touching a
forbidden path. The direct read still takes priority, so nothing changes where it
works; measured on a desktop machine, the two methods agree to the second. The
parsing splits on the **last** `)` rather than on whitespace: field 2 is the
executable's name in parentheses and may contain spaces and parentheses, the one
case that makes a naive split read the wrong field.

`src/modules/status.js` polls that route every 10 s by default (settable) and
shows one line per datum, each independently hideable.

**Degraded mode.** The link line switches to `OFFLINE` as soon as a request fails
— immediately, not after three attempts — or, without a single failure, as soon
as a snapshot exceeds three times the interval with no fresh response having
arrived in the meantime. In both cases the module does not empty itself: it keeps
the last known values, marks them with their age (`> AGE   42s`), and switches
the link line to `OFFLINE`. The battery then falls back to the browser API if it
exists (`(NAV)` marker in the line). A stopped server degrades the display, it
does not erase it — the same rule as for a corrupted configuration.

### What the device confirmed, and what it will not give

`termux-battery-status` and `termux-wifi-connectioninfo` were verified on the
device: percentage, charging state, temperature, RSSI and link speed all answer.
The SSID additionally requires the location permission granted to Termux:API
(Android has reserved it for location-aware apps since version 9, a network's
name being enough to infer a place); once granted, it comes through.

Two readings are **not** obtained, and will not be:

- **Processor load.** SELinux grants `/proc/meminfo` to an unprivileged app and
  denies it `/proc/stat` and `/proc/loadavg` — a denial confirmed on the device
  by an audit entry (`avc: denied { read } … app=com.termux`). Android exposes no
  equivalent public API. So the line is off by default rather than showing a
  permanent `N/A`; the setting remains, the probe working on a desktop machine
  and on a rooted phone.
- **`/proc/uptime`**, denied for the same reason — but that one is worked around,
  see above.

## Settings

The ⚙ button, bottom right. The panel is generated from declarations; here is
what each section actually controls, in the order it appears. Section and option
names are given as they appear on screen, in French.

**Thème** (theme) — Palette (Matrix / Night City / Arasaka); Teinte, the hue
(0-359°, an "auto" position to return to the palette's native hue). Only the ink
rotates, the background stays the palette's.

**Ambiance** (ambience) — Fond animé, the animated background (on/off); Portée,
its scope ("Colonne" confines the rain to the right band, the default; "Plein
écran" extends it behind the whole interface — full Matrix mode, which brings
back the cost the first design warned against); Densité, Vitesse, Traînée
(density, speed, trail); Glyphes (Katakana / hexadecimal / ASCII); Résolution (a
multiplier on CSS pixels, never on the screen's ratio); Images/s (frame-rate cap,
10 to 60).

The rain has its own colour, `--rain`: the theme's `--fg` hue shifted 14° round
the colour wheel and darkened to 70 % of its lightness (`RAIN_HUE_SHIFT` and
`RAIN_LIGHTNESS`, in `theme.js`). In Matrix that gives `#00b357` against the
text's `#00ff41` — another shade of the same family, not a second colour
competing for attention. Without that gap the rain borrowed exactly the text
colour and merged into it as soon as it passed behind the status column.

It is computed rather than hard-coded three times: the arithmetic is the same in
every palette, and above all it is derived from the `fg` **after** rotation, so
the gap survives the Teinte slider — which brings every rotated key back onto the
single chosen hue, and would therefore have aligned the rain with the text had it
figured in that list. The glyphs keep 15 % transparency (`GLYPH_ALPHA`, in
`rain.js`), just enough to soften their edges; the separation comes from the
colour.

**Effets** (effects) — five switches, actually wired since this redesign
(declared in the panel long before, they did nothing):

| Effect | What it does on screen |
|---|---|
| Scanlines | Repeated horizontal bands, CRT-monitor style. A single layer painted once, never animated. |
| Grain | A faint noise texture (SVG turbulence), tinted by the theme colour. |
| Vignettage | Darkens the screen's edges towards the theme's background colour. |
| Lueur | A glow (`text-shadow`) on the logo and the time only, and off by default. Both are big enough to carry it; on 10 px text the glow fills the inside of the letters instead of surrounding them, which made the status lines and the journal unreadable. |
| Glitch | Every ~4 s, a brief positional shift and an opacity flicker, on the logo and the clock only. |

**Disposition** (layout) — Three separate ink settings, all white by default, all
switchable to the theme colour: **Encre**, **Encre du logo**, **Encre de
l'avatar** (ink, logo ink, avatar ink). The first paints everything that is
*content* without being one of the other two: the header (barcodes and code
groups), the time and date, and the coarse row of the footer's ribbon. What
belongs to the *structure* — frame, brackets, gauge, rules, the ribbon's fine row
— keeps the palette colour, whatever the setting. That is the split from the
reference photo, where the content is white and the chassis green.

White is a literal value: "something other than the palette colour" has no answer
*within* the palette. Three tokens and not one (`--ink`, `--logo-ink`,
`--avatar-ink`, in `theme.css`) because the logo and the avatar are precisely the
two elements one wants to distinguish — from the rest of the deck, and from each
other.

The canvas avatars do not read a CSS variable: they paint with a colour string.
So only the avatar ink is also written into the palette object
(`colors.avatarInk`, in `main.js`) — the other two are read by stylesheets only,
and adding them there would mean two more values to keep in step with the
attributes, with no reader. Since `engine.js` re-reads `getColors()` every frame,
they follow with nothing more. Mind the trap: `resolveTheme` returns a fresh
object, so changing palette erases the ink written on the previous one —
`applyInk` is called again right after, failing which the canvas avatars would
stay on the old palette's colour until the next layout change.

Shortcut grid columns: **Auto** by default, or 2, 3, 4. In Auto, `bestFit` (in
`shortcuts.js`) tries every possible column count, computes for each the
resulting tile size — the smaller of the two constraints, width and height — and
keeps the one giving the largest tiles. A fixed number is honoured as given, only
its size being computed; if the band is too narrow to draw it legibly it falls
back to what the band can carry.

It is a computation and not a CSS rule because that is what it is: choosing
columns means comparing, for each candidate, the resulting size against both
dimensions at once. The old grid looked only at the width and kept the tiles
square through `aspect-ratio`, so its height was whatever the width implied — past
a few shortcuts, it overflowed the band and the column scrolled. The grid now
scrolls in one case only: when fitting everything in would take the tiles below
their minimum size. A tile too small to touch, or too small for its own label, is
worse than a scrollbar.

That minimum is 3.5 rem (56 px), not the 44 px of the touch target: a finger
reaches 44 px, but the tile cannot draw itself there — its icon and its label hit
their own legibility floors and overflow it, and the overflow of a grid item
propagates up to the band. The touch target is a floor beneath this one, not the
other way round.

Also: Taille de l'horloge, the clock size (Petite / Moyenne / Grande — a scale on
the clock+date line, more a composition element); Style du logo (the four
treatments above).

**CIPHER-2** — Avatar (the twelve above); Journal (on/off).

**Chrono** (timing) — Afficher les secondes, show seconds (on/off). The time is
always 24 h and the date always `DD/MM/YYYY`; neither is settable. The date is
assembled from the local accessors rather than by `toLocaleDateString`, whose
result would follow the phone's locale.

**État système** (system status) — Interval in ms (2,000 to 60,000); one checkbox
per line (IP, battery, Wi-Fi, processor, memory, storage, uptime — hidden by
default — and link state).

**Raccourcis** (shortcuts) — no checkbox: a built-in editor (icon, label, target
on its own line, arrows to reorder, a cross to delete, a button to add).

**Système** (system, at the bottom of the panel, outside any module) — copy or
download the configuration, import one, reset everything. See *Backup*.

## Shortcuts

**Defaults, from the very first launch:**

| Label | Target |
|---|---|
| YT Music | `https://music.youtube.com/` |
| Météo | `https://meteofrance.com/` |
| Actu | `https://news.google.com/` |
| Termux | `intent://#Intent;package=com.termux;end` |

The ids (`yt-music`, `meteo`, `actu`, `termux`) are fixed literals in
`defaults()`, not generated: two installations start from the same state,
identically.

**Targets.** The "target" field is handed to the system without interpretation,
except for the `javascript:`, `data:`, `vbscript:` and `file:` schemes, which are
refused. That refusal is applied at the level of the configuration itself
(`validateShortcut`, in `schema.js`), so uniformly whatever the target's origin —
creation, later edit of an existing shortcut, or import of a whole configuration:
a shortcut carrying one of those schemes is simply dropped from the list, never
displayed.

| Form | Example | Note |
|---|---|---|
| Full URL | `https://music.youtube.com/` | Always reliable — the first three default shortcuts. |
| Bare domain | `youtube.com` | `https://` is added automatically only when creating a shortcut from the editor (`normalizeTarget`); editing an existing target writes it as-is, without that prefix. The default targets are already written in full. |
| App link | `https://open.spotify.com/…` | Android opens the native app if it is installed and the link is declared for it. The recommended route. |
| App scheme | `spotify:track:…` | Depends on the installed app. |
| Android intent | `intent://#Intent;package=com.termux;end` | The default "Termux" shortcut is the test of this. Unverified: whether it works from a PWA installed in standalone mode has not been confirmed. |

## Backup

The whole configuration lives in **a single key** of Chrome's local storage
(`cyberdeck.config.v1`). **Clearing the cache or reinstalling erases it without
warning.** The panel's "Système" section offers two ways out: "Copier la
configuration" (clipboard, the main route) and "Télécharger" (download, a
fallback if the clipboard fails). **That is the only backup there is** — use it
after any run of changes to the settings or the shortcuts.

## Installing on the phone

1. Install **Termux from F-Droid**. The Play Store version is abandoned and
   receives no more packages.
2. Install **Termux:API from F-Droid** as well — the companion app, separate from
   Termux itself. Without it, the `termux-*` commands installed in the next step
   exist but return nothing: no visible error, just a `null` field in
   `/api/status`.
3. In Termux:
   ```sh
   pkg update && pkg install python openssh rsync termux-api
   ```
4. Start Termux's SSH server (`sshd`), note the user name (`whoami`) and the IP
   address (`ifconfig`), then from the workstation:
   ```sh
   rsync -av --delete -e 'ssh -p 8022' gui/ <user>@<ip>:~/cyberdeck-gui/
   ```
   Termux's SSH port is 8022, not 22 — hence the `-e 'ssh -p 8022'`: the
   `host:port:path` form does not exist for `rsync`, which splits the target on
   the colon and would read `8022` as a directory. Network-free alternative: copy
   the folder over a cable with MTP.
5. In Termux, from `~/cyberdeck-gui`:
   ```sh
   ./serve.sh
   ```
6. In Chrome, open `http://localhost:8080`.
7. Chrome's menu → "Install app".

## Updating, and how the server runs

**The server now has to run permanently.** This reverses what the first version
of this README claimed: it is no longer a file server you start to install or
update and then shut down. The status column polls `/api/status` continuously,
and that route only exists while `tools/serve.py` is running.

With the server off, the page still opens, full screen, from the service
worker's cache — the installation stays usable. But the status column shows its
last known values with their age, and the link line goes to `OFFLINE` on the
first failed request (immediately, then — the three-interval rule applies only to
silence without an explicit failure, see *System status*). That is not a fault:
it is the degraded mode documented above, which triggers whenever Termux is not
running.

**The worker goes to the network first, the cache second.** It used to be the
other way round, and cache-first was simply the wrong policy here: the server
runs on the same device, on `127.0.0.1`, over the loopback interface. There is no
latency to save and no bandwidth to spare, so preferring the cache bought nothing
— at the cost of the only thing that matters, namely that the files on disk are
the ones you see. Every change required a `CACHE_VERSION` bump **plus** a second
load, and getting either wrong gave a page mixing new and old files.

So the cache is now consulted only when there is no server to ask — the case it
exists for: the deck opens before Termux has been started. Verified with the
server fully stopped: logo, avatar, clock and shortcuts all appear, and the
verdict announces of its own accord "Link lost, running blind, Operator." It
refreshes on every successful response, so the offline copy follows the running
version rather than the one frozen at install time. Only 200s are stored: caching
a 404 would serve it indefinitely. `/api/status` is excluded — a stale reading
served offline would not be a degraded answer but a false one, and `status.js`
already has its own degraded mode for that failure.

### Automatic startup

`tools/boot/` holds the scripts **Termux:Boot** runs when the device starts.
Install the add-on from F-Droid, **open it once by hand** (it does not arm
otherwise), then, in Termux:

```sh
sh ~/cyberdeck-gui/tools/boot/install.sh
```

They read from the deck's own directory rather than from `/sdcard`, by design:
Termux has no guarantee of access to shared storage. On the reference device
(MIUI) it was granted `WRITE_EXTERNAL_STORAGE` and **denied**
`READ_EXTERNAL_STORAGE` — a script placed in `/sdcard/Download` was therefore
unreadable, where the deck's files, in Termux's private directory, always are.

`10-deck-server.sh` takes a `termux-wake-lock` before launching the server:
without that lock, Android puts the process to sleep as soon as the screen goes
off and the deck no longer answers on wake. Termux's **autostart** must also be
enabled in the OEM's settings, without which nothing will wake it at boot. (The
power-saving exemption was already granted on the reference device.)

`20-deck-launch.sh` opens the deck twelve seconds later, and that is the fragile
half: Android 10+ restricts launching an activity from the background, and OEM
skins gate it behind a permission of their own (on MIUI, "display pop-up windows
while running in the background"). If nothing opens, deleting that file leaves the
server to start on its own. Install the PWA **before** testing this script: once
the WebAPK is in place the URL opens in the app, full screen; without it, it
would open in Chrome with its address bar.

The script's `WEBAPK_PKG` is empty on purpose. Chrome mints the WebAPK's package
name from a hash of the manifest, so it belongs to one install and is re-minted
whenever the manifest changes; read yours with `adb shell pm list packages | grep
webapk`. Left empty, the script falls back to the ambiguous open, which works
once the chooser has been answered with "always".

To publish a code update:

1. Redeploy the changed files (`rsync`, see above) and restart `./serve.sh` if
   the server had been stopped.
2. Open the app. It reloads itself once as soon as the new worker takes over
   (`controllerchange`, in `main.js`), so the update applies on the first launch
   and not the next.

Without that reload, `skipWaiting()` + `clients.claim()` had the new worker adopt
the page while it was already running the previous version's HTML, CSS and
modules — nothing replaced them before the next navigation. This was not
theoretical: we obtained a page holding a new `registry.js` (a file the old worker
had never cached, so served from the network) next to an old `avatars.css` (a file
it had), and therefore avatars whose animations simply did not exist in the
stylesheet. The guard matters: `clients.claim()` also fires `controllerchange` on
the very first visit, when the page started with no controller, and reloading
there would be a reload on every first visit, for nothing.

One nuance: the automatic reload cannot help the transition *to* the version that
introduces it, since it is the old page that is running at that moment and it does
not yet contain the listener. It counts from the following update onwards.

`CACHE_VERSION` no longer governs whether an update is visible; it only names the
offline copy, to be bumped only to discard it deliberately. That was not always
the case, and the trap is worth remembering: `cache.addAll()` goes through the
browser's HTTP cache, and `tools/serve.py` used to send `Cache-Control` on `sw.js`
only, so the browser applied its heuristic caching to the rest and the worker
faithfully copied stale files into a cache bearing the new version name. Symptom:
`caches.keys()` announces `cipher2-v25` and the screen still shows the previous
version. Fixed on both sides — `no-cache` on every file served, and a precache
built on `Request(url, { cache: 'reload' })` so the worker stays correct whatever
server is in front of it.

## Tests

```sh
node --test "gui/test/**/*.js"
```

No npm dependency. `python3` must be on the `PATH`: some tests launch the real
`tools/serve.py` as a subprocess and query it over HTTP rather than simulating
the server.

**Covered automatically**: the configuration and its validation (including the
four default shortcuts), the store and its degraded modes, the theme's colour
conversions, the module registry (mount band, view cycle, tolerance of modules
that throw), the avatar registry (all of them, agreement with the schema,
SVG/canvas contract), the clock, the logo, the rain and the ambience engine
(frame-rate cap, resizing, off-screen suspension), the five surface effects
(configuration → CSS classes), the parsing and staleness of the `/api/status`
telemetry, the settings panel (declarations, enabling/disabling a module), export
and import, and the agreement between the files actually served and `sw.js`'s
precache list.

The `/api/status` route and `tools/serve.py` itself are covered **as a black box
from Node** (`test/api.test.js`, `test/serve.test.js`): the real Python process is
launched and queried over HTTP, never simulated. **`tools/status.py`, the
collector, has no unit tests of its own** — its functions (`battery()`, `wifi()`,
`cpu()`…) are exercised only indirectly, through the full JSON response those
black-box tests observe. On a development machine the `termux-*` commands do not
exist, so only the degraded path (`null` field) is really exercised by the suite;
the populated path is exercised only on the phone (see *System status*).

**Not covered automatically**, as in the first version: rendering, the DOM, the
canvas, actually opening a target, and everything `termux-api` returns once
really installed. Hence the list below.

## Manual checks

To be run again after any change touching rendering:

- [ ] The page opens full screen from the home-screen icon.
- [ ] The landscape fit holds at several screen sizes (at least the reference
      phone and a much larger window): band and footer always visible, nothing
      pushes the footer off screen.
- [ ] The background rain runs smoothly; the phone does not heat up after ten
      minutes.
- [ ] "Ambiance" scope: "Colonne" confines the rain to the right band; "Plein
      écran" (full Matrix mode) extends it behind the whole interface.
- [ ] Lowering Résolution and Images/s visibly lightens the animation.
- [ ] Screen off then on again: the animation had stopped and resumes.
- [ ] Changing palette repaints everything, including the tiles and the avatars.
- [ ] The hue slider changes the ink and leaves the background black; "auto"
      returns to the native hue.
- [ ] Each CIPHER-2 avatar selects, mounts and unmounts cleanly (no orphaned
      animation or canvas after repeated changes).
- [ ] CIPHER-2's journal goes off with its setting.
- [ ] Each effect acts immediately and visibly: scanlines, grain, vignette, glow,
      glitch.
- [ ] View switching works both from the keyboard (`Enter` from the status,
      `Escape` from the shortcuts) and by touch (tapping the prompt at the foot of
      the view) — both must produce the same result.
- [ ] `Enter` typed in a settings-panel field stays usable for typing and does
      not switch the view behind the panel.
- [ ] Status column: stop the Termux server and observe the degraded mode — last
      values kept, age shown, link line on `OFFLINE`, screen never emptied.
- [ ] A long press on a tile opens the panel on that tile's field.
- [ ] A short tap on a tile opens the target, without opening the editor or
      changing view.
- [ ] The arrows reorder the shortcuts; the cross deletes one.
- [ ] Disabling a module removes it from the screen and keeps its settings;
      re-enabling it restores its original position, not the end of the list.
- [ ] Reloading the page preserves the whole configuration.
- [ ] "Copier la configuration" then "Importer" restores the same state.
- [ ] Importing `{ broken` shows a refusal and changes nothing.
- [ ] Stop Termux, force-close the app, reopen it: it opens from the cache, status
      column in degraded mode from the start.

## Still unverified

Two points cannot be checked from a development machine, and are marked as such
where they appear above:

1. **Installing from `localhost`** — whether Chrome accepts installing this page
   as an app from a `localhost` address. See *Installing on the phone*.
2. **`intent://` in standalone mode** — whether an `intent://` target opens from
   the app installed in standalone mode. The default "Termux" shortcut is the
   test. See *Shortcuts*.

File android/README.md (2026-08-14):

# cyberdeck-reporter

Companion app for the `arduino/screen_wake` rig: it tells the board what the
phone is doing (screen on or off, battery level), so the button's LED can show
it. The protocol is one-way — the app talks, the board listens — the opposite
direction from the Power key the button sends to the phone.

## What each component does

| File | Role |
|---|---|
| `ReporterService` | The real work. A *foreground* service that listens for `ACTION_SCREEN_ON`/`ACTION_SCREEN_OFF`, polls the battery and writes one line every 5 s to the serial port. |
| `MainActivity` | Diagnostic screen: service state, link state, last line sent and its age, plus the two **Start reporting** / **Stop reporting** buttons. Holds no serial connection of its own. |
| `BootReceiver` | Restarts the service at boot (`BOOT_COMPLETED`), provided the OEM allows it — see below. |
| `SerialLink` | Opens the USB serial port and writes bytes to it. Has never heard of screens or batteries: `ReporterService` carries all the domain knowledge. |
| `Protocol` | Formats a line. A pure function, no Android dependency. |

`ReporterService` runs in the *foreground* (with a permanent notification)
because `ACTION_SCREEN_ON`/`ACTION_SCREEN_OFF` can no longer be declared in the
manifest since API 26: only a live component can register them dynamically, and
an ordinary (non-foreground) service would be killed by the system within
minutes. The permanent notification is the price of that constraint, not a
comfort choice.

## The protocol it sends

One text line per event, formatted by `Protocol.line()`:

```
S<0|1> B<0..100>\n
```

| Field | Meaning |
|---|---|
| `S0` / `S1` | Screen off / on |
| `B<pct>` | Battery in %, clamped to [0, 100] by `Protocol.line` — a guard so no number the firmware would reject ever goes on the wire, not the "unknown level" policy (see below) |

Cadence:

- **Every 5 s** (`HEARTBEAT_MS`): an unconditional heartbeat, screen on or off.
- **Immediately** on each screen transition (`ACTION_SCREEN_ON` /
  `ACTION_SCREEN_OFF`), without waiting for the next heartbeat.

That heartbeat carries a double load: it transmits the current state, and its
absence is the board's only way of knowing the app has died. 15 s of silence
(`APP_TIMEOUT_MS` in `arduino/screen_wake/led_state.h`) puts the LED into its
4 Hz fault blink.

The battery is polled at heartbeat time
(`BatteryManager.getIntProperty(BATTERY_PROPERTY_CAPACITY)`), not watched by a
second receiver: a change in percentage therefore takes up to 5 s to be
reported rather than being instant. Accepted, because the only consumer of that
value on the board side is a threshold alert (`BATT_LOW_PCT`/`BATT_CLEAR_PCT`),
not a real-time display.

### When the level is unknown

`getIntProperty` does not return -1 on failure but `Integer.MIN_VALUE`. Clamped,
that gives `B0`: the board reads it as a critical battery, arms its alert and —
through hysteresis — holds it until it receives a value above 20 %. A failed
reading would therefore raise a lasting false alarm on a perfectly charged
phone.

So `ReporterService` keeps the **last credible value** (the one within `0..100`)
and repeats it until it gets a better one. Before any valid reading it announces
50 %: any value above `BATT_CLEAR_PCT` would be just as safe, but 50 reads as
the placeholder it is — 100 would assert a full charge that was never measured,
and 0 would be exactly the fault being avoided here. In practice that 50 only
goes on the wire if the very first reading fails, the first heartbeat happening
as early as `onCreate`.

If the port is not open at heartbeat time (board unplugged, USB permission not
granted yet), that same heartbeat reschedules itself 3 s later
(`RECONNECT_MS`) instead of the usual 5 s — never in addition to the normal
heartbeat: exactly one callback is pending at any moment, including right after
a screen toggle, which triggers an immediate report but reschedules nothing
itself. The 5 s rhythm resumes as soon as a report succeeds.

### Where all this runs

Everything touching the serial port runs on a dedicated `HandlerThread`
(`reporter-serial`), never on the main thread. `SerialLink.open()` chains two
USB control transfers, and the library grants them **5 s each** (the 500 ms
`WRITE_TIMEOUT_MS` covers data writes only): a board that accepts the interface
claim but answers no control request — the exact state of a 32U4 board
re-enumerating after an upload — blocks the caller for ten seconds. On the main
thread that is an ANR; and an app in ANR is precisely what an aggressive OEM
power manager kills, so the failure would attack the very property this service
exists to defend.

`onReceive` stays on the main thread, but does only two things there: note the
screen state (a `@Volatile` field) and post the report to the worker. The posted
report is a single-use `Runnable` that reschedules nothing — the heartbeat
remains the only scheduler, so a screen toggle cannot start a second chain of
heartbeats. Since both share the same queue, they never run in parallel:
`SerialLink` needs no lock.

On shutdown, `onDestroy` removes the pending heartbeat, posts the port close to
the worker, then calls `quitSafely()` — so the close happens on the thread that
opened the port, behind any report still in flight, instead of racing it from
the main thread.

## Diagnostic screen

`MainActivity` shows three lines, refreshed twice a second while the screen is
visible:

```
service   : running
link      : port open
last line : S1 B87   2s ago
```

| Line | What it says |
|---|---|
| `service` | `running` as soon as `ReporterService.onCreate` has run, `stopped` otherwise |
| `link` | `port open`, or the exact reason for the last failure to open: `no USB permission yet; replug the board`, `no Arduino found on the bus`, `openDevice returned null`, `write failed -- board unplugged?` |
| `last line` | The last line actually written to the port, and how long ago |

The age of the last line is what tells a live heartbeat from a frozen one: the
screen and the battery rarely change, so the text of the line itself does not
move.

The most likely silent failure — USB permission never granted, so `open()`
failing every 3 s indefinitely — reads straight off this screen. Before, it left
only a warning in `logcat`, out of reach on a phone whose single USB port is
taken by the board.

The activity **polls** these values rather than subscribing to them: a dead
service sends no notification, and the absence of a notification would look
exactly like a service with nothing to say.

## Required OEM settings

Tested on MIUI, but the problem is not specific to it: OEM Android skins —
MIUI, One UI, EMUI, ColorOS and others — routinely stop apps of this kind,
foreground service or not. No endurance measurement has been made here, so no
delay is claimed. What is certain: without the three settings below,
`BootReceiver` never receives `BOOT_COMPLETED`. None of them can be set from
code — the OEM treats them as explicit user choices.

The menu paths below are MIUI's; other skins have equivalents under similar
names.

| Setting | Path | Why |
|---|---|---|
| **Autostart** | Settings → Apps → Cyberdeck Reporter → Autostart | Without it, the OEM blocks the `BOOT_COMPLETED` broadcast to `BootReceiver` — the service never restarts after a reboot, even with correct code. |
| **Battery saver: No restrictions** | Same screen | The OEM has its own power manager, independent of Android's: even a foreground service with a visible notification can be stopped if the app stays in the default restricted profile. |
| **Lock the recents thumbnail** | Recents screen → drag the app's thumbnail down → padlock icon | Prevents the "swipe to close" gesture in recents, which bypasses Android's normal lifecycle and kills the service without going through `onDestroy()`. |

## Building and installing

```bash
export JAVA_HOME=/path/to/jdk-21          # see below
cd android
./gradlew assembleDebug
adb install -r app/build/outputs/apk/debug/app-debug.apk
```

`-r` reinstalls over an existing version without wiping data — useful when
iterating, so the OEM settings above are not lost on every install.

The SDK location goes in `android/local.properties`, which is not tracked:

```properties
sdk.dir=/path/to/Android/Sdk
```

### Which JDK actually works

`JAVA_HOME` must point at a **JDK 21** (Temurin 21 was used here). A Java 25
JDK does not work: Gradle 8.14's bundled Kotlin DSL compiler raises
`IllegalArgumentException: 25.0.3` in `JavaVersion.parse` as early as `gradle
wrapper`, before the Android plugin is even consulted. This matters in practice
because JetBrains IDEs ship a JBR that may well be Java 25, and pointing
`JAVA_HOME` at it is the obvious mistake. JDK 21 compiles the project with no
adjustment.

### A note on `buildToolsVersion`

`app/build.gradle.kts` pins `buildToolsVersion = "35.0.1"`. That setting does
**not** align the version of aapt2 (the resource compiler) used by the build
with the one in the SDK's `build-tools/35.0.1/` directory. AGP resolves its own
packaging aapt2 as a Maven dependency
(`com.android.tools.build:aapt2:<AGP version>-<build number>`), locked to the
AGP version, never read from an SDK `build-tools/` directory — behaviour
confirmed by inspecting the AGP 8.7.3 jar itself (class `Aapt2FromMaven`, which
builds the Maven coordinate from its own plugin version and a build number
embedded in `aapt2_version.properties`, without ever referencing
`buildToolsVersion`).

What the pin actually does, and all it does: without it, AGP falls back to its
default build-tools version and installs it into the local SDK silently, if the
licence has already been accepted — observed on this project, where an unpinned
build installed `build-tools 34.0.0` unasked. Pinning a version that is already
present removes that automatic install cycle. It is a guard on the state of the
local SDK, not an aapt2 alignment.

## Wireless debugging

The rig occupies the phone's only USB port during verification: there is no way
to plug an `adb` cable in at the same time. Android 11's wireless debugging lets
you follow the logs without unplugging the rig.

```bash
adb pair <ip>:<port>        # code shown on the phone
adb connect <ip>:<port>
adb logcat -s ReporterService SerialLink
```

The phone shows the IP, the port and the pairing code under Settings →
Developer options → Wireless debugging. Phone and workstation must be on the
same Wi-Fi network.

## Tests

Only `Protocol` is covered by JVM tests (`ProtocolTest`, 4 cases: screen on,
screen off, clamp high, clamp low) — it is the module's only class with no
dependency on the Android framework. `SerialLink`, `ReporterService` and
`BootReceiver` touch USB, system broadcasts or the OEM lifecycle: they can only
be verified with the phone and the board in hand, rig plugged in, the OEM
settings above applied, watching the LED (priority table in
`arduino/README.md`).

```bash
./gradlew test
```

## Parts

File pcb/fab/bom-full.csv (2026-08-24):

Ref | Value | Footprint | DNP
C1 | 100nF | Capacitor_SMD:C_1206_3216Metric
J1 | TRACKBALL | Connector_PinHeader_2.54mm:PinHeader_1x05_P2.54mm_Vertical
J2 | SPARE | Connector_PinHeader_2.54mm:PinHeader_1x06_P2.54mm_Vertical
J3 | ENCODER | Connector_PinHeader_2.54mm:PinHeader_1x05_P2.54mm_Vertical
J4 | BUTTON | Connector_PinHeader_2.54mm:PinHeader_1x04_P2.54mm_Vertical
R1 | 150R | Resistor_SMD:R_1206_3216Metric
R2 | 4k7 | Resistor_SMD:R_1206_3216Metric | DNP
R3 | 4k7 | Resistor_SMD:R_1206_3216Metric | DNP
SJ1 | OPEN | Jumper:SolderJumper-2_P1.3mm_Open_Pad1.0x1.5mm | DNP
U1 | Pro Micro 5V/16MHz | cipher2:ProMicro_2x12_P2.54mm

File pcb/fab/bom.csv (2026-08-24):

Refs | Value | Footprint | Qty
C1 | 100nF | Capacitor_SMD:C_1206_3216Metric | 1
J1 | TRACKBALL | Connector_PinHeader_2.54mm:PinHeader_1x05_P2.54mm_Vertical | 1
J2 | SPARE | Connector_PinHeader_2.54mm:PinHeader_1x06_P2.54mm_Vertical | 1
J3 | ENCODER | Connector_PinHeader_2.54mm:PinHeader_1x05_P2.54mm_Vertical | 1
J4 | BUTTON | Connector_PinHeader_2.54mm:PinHeader_1x04_P2.54mm_Vertical | 1
R1 | 150R | Resistor_SMD:R_1206_3216Metric | 1
U1 | Pro Micro 5V/16MHz | cipher2:ProMicro_2x12_P2.54mm | 1

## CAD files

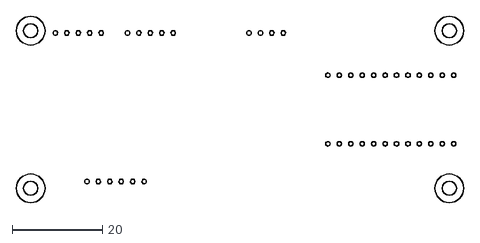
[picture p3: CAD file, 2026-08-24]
pcb/mech/cipher2-panel-User_Comments.dxf
99.4 x 41.4

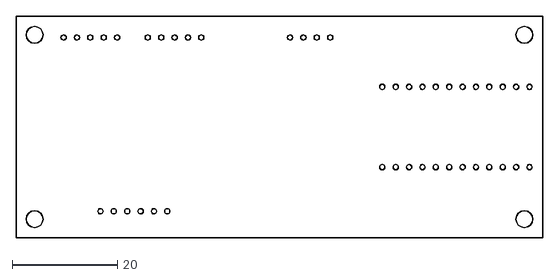
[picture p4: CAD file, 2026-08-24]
pcb/mech/cipher2-panel-Edge_Cuts.dxf
100.0 x 42.0

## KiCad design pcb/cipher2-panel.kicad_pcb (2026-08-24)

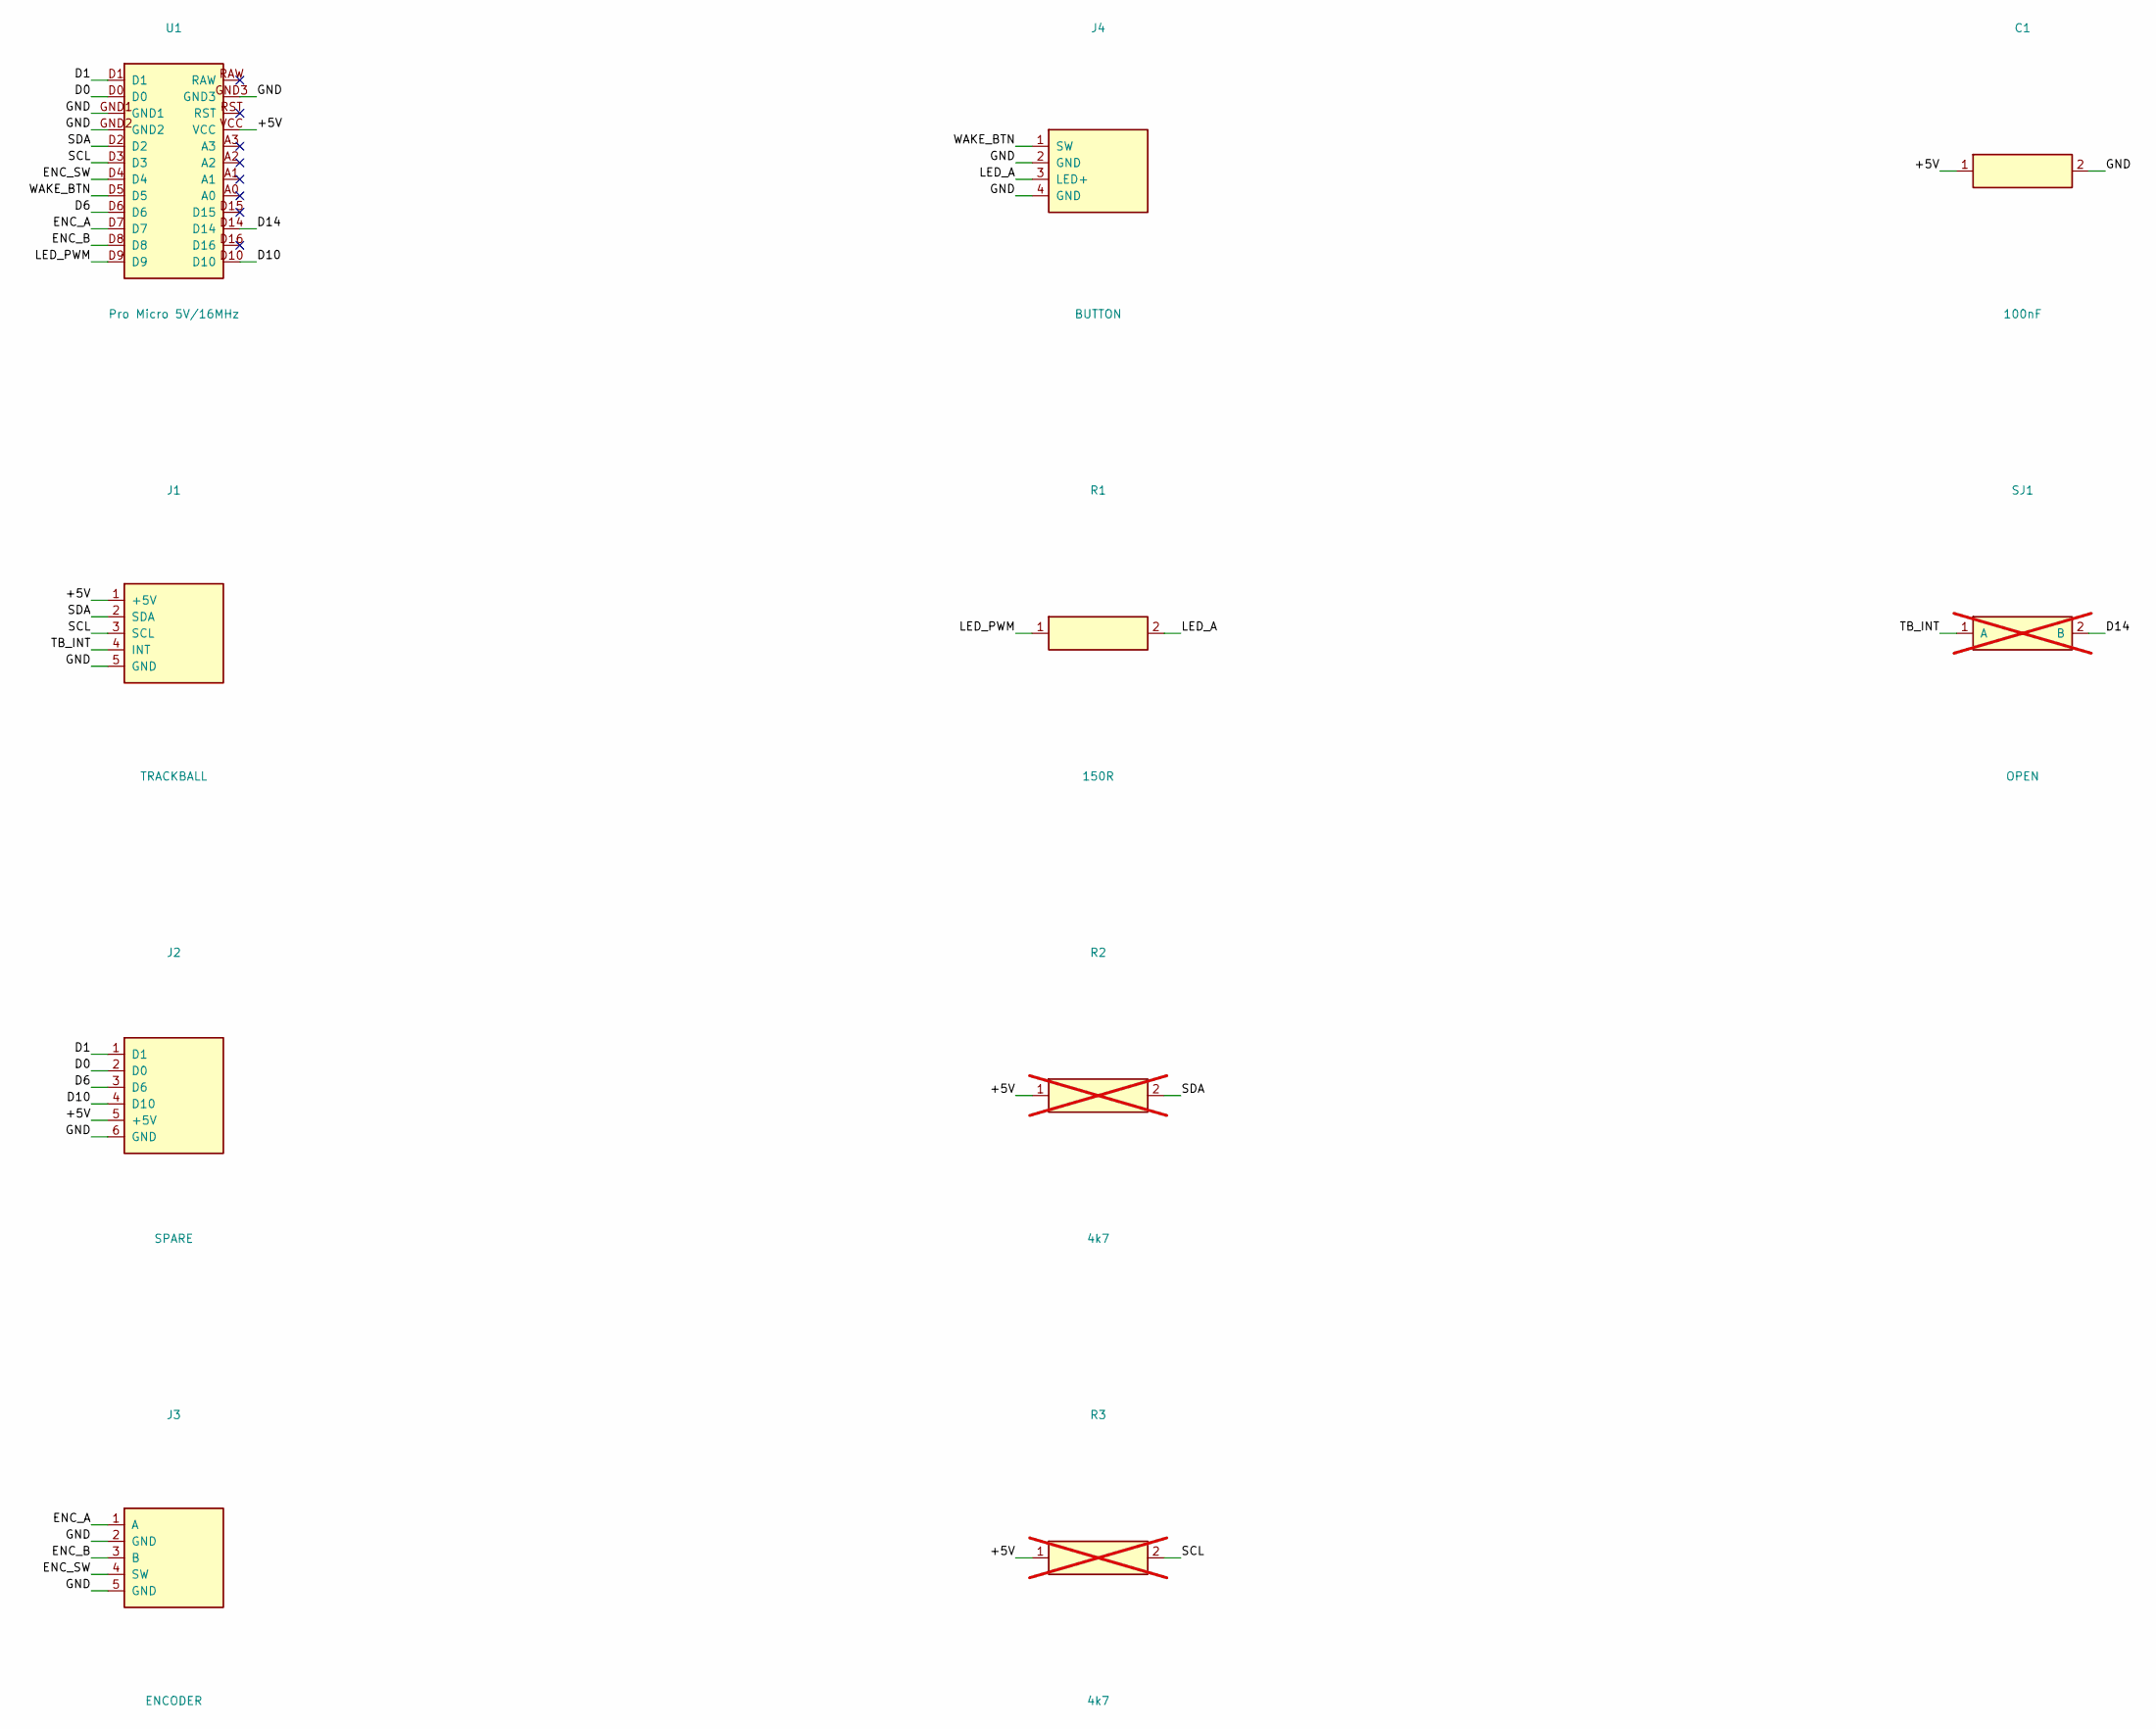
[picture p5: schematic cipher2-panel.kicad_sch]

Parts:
C1: 100nF; C_1206_3216Metric
J1: TRACKBALL; PinHeader_1x05_P2.54mm_Vertical
J2: SPARE; PinHeader_1x06_P2.54mm_Vertical
J3: ENCODER; PinHeader_1x05_P2.54mm_Vertical
J4: BUTTON; PinHeader_1x04_P2.54mm_Vertical
R1: 150R; R_1206_3216Metric
R2, R3: 4k7; R_1206_3216Metric; not fitted
SJ1: OPEN; SolderJumper-2_P1.3mm_Open_Pad1.0x1.5mm; not fitted
U1: Pro Micro 5V/16MHz; ProMicro_2x12_P2.54mm

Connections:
/+5V: C1.1, J1.1 (+5V), J2.5 (+5V), R2.1, R3.1, U1.VCC
/D0: J2.2 (D0), U1.D0
/D1: J2.1 (D1), U1.D1
/D6: J2.3 (D6), U1.D6
/D10: J2.4 (D10), U1.D10
/D14: SJ1.2 (B), U1.D14
/ENC_A: J3.1 (A), U1.D7
/ENC_B: J3.3 (B), U1.D8
/ENC_SW: J3.4 (SW), U1.D4
/GND: C1.2, J1.5 (GND), J2.6 (GND), J3.2 (GND), J3.5 (GND), J4.2 (GND), J4.4 (GND), U1.GND1, U1.GND2, U1.GND3
/LED_A: J4.3 (LED+), R1.2
/LED_PWM: R1.1, U1.D9
/SCL: J1.3 (SCL), R3.2, U1.D3
/SDA: J1.2 (SDA), R2.2, U1.D2
/TB_INT: J1.4 (INT), SJ1.1 (A)
/WAKE_BTN: J4.1 (SW), U1.D5

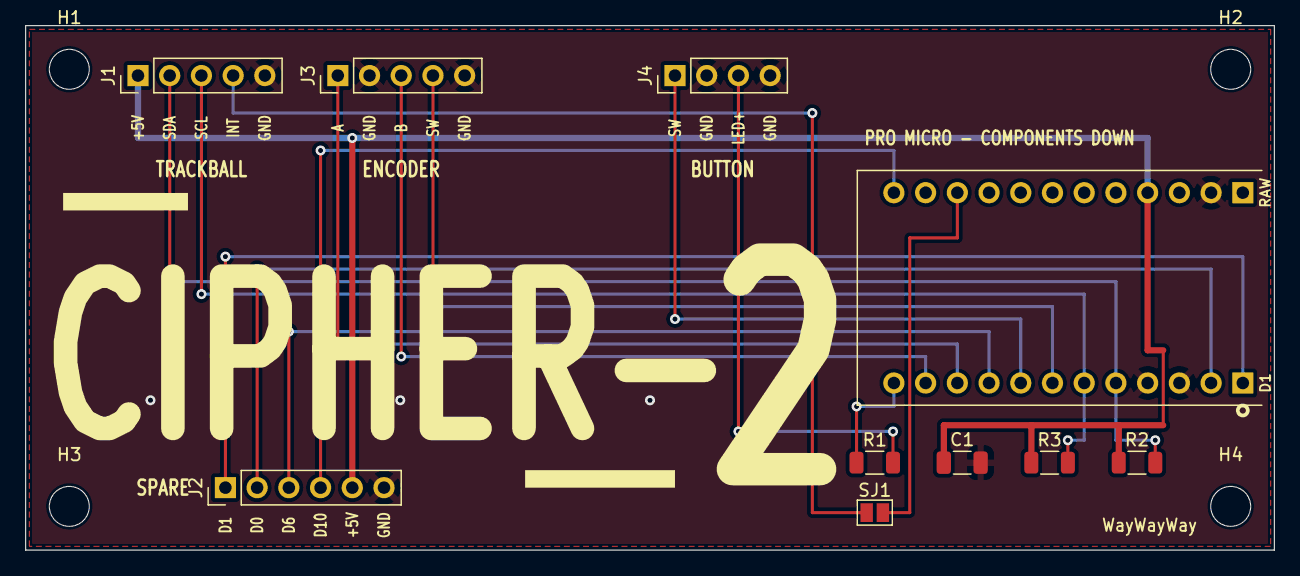
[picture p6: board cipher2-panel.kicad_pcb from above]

Board: 2 copper layers, 100.0 x 42.0 mm, 14 parts (0 on the bottom side), 16 nets.

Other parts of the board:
H1, H2, H3, H4: MountingHole_3.2mm_M3

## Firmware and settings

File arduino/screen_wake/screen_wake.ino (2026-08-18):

/*
  cyberdeck / screen_wake

  A momentary button on an ATmega32U4 board (Arduino Leonardo / Pro Micro).
  The board enumerates on the phone as a USB HID consumer-control device and
  sends the Power key. Android maps that to KEY_POWER, which carries the WAKE
  flag in the default key layout, so a press behaves like the phone's own
  power button: screen on if off, off if on.

  The companion Android app reports the phone's screen and battery over the
  serial port; the LED shows what it says. All decision logic lives in
  led_state.h, which builds on the host and is tested there.

  A rotary encoder rides alongside: turning it steps the phone's volume,
  pressing it mutes. Both are the same Consumer keys the wake button uses.

  A Pimoroni PIM447 trackball hangs off the I2C bus. The ball moves a pointer,
  and its single contact carries three gestures: a short press is a left click,
  a hold is a right click, and pressing then rolling is a drag. Its RGBW ring
  shows the battery level. Its chip ID is the presence test, so a rig without
  one behaves unchanged.

  Wiring (every button and encoder input uses the internal pull-up, no
  external resistor):
    button contact   -> D5 and GND
    LED anode        -> D9 via 150 ohm
    LED cathode      -> GND
    encoder A        -> D7
    encoder common   -> GND
    encoder B        -> D8
    encoder switch   -> D4 and GND
    trackball SDA    -> D2
    trackball SCL    -> D3
    trackball power  -> 5V and GND

  D2 and D3 carry the ATmega32U4's only hardware I2C bus, which is why the
  wake button lives on D5 rather than where it started.

  Build and upload:
    arduino-cli compile --fqbn arduino:avr:leonardo screen_wake
    arduino-cli upload  --fqbn arduino:avr:leonardo -p /dev/ttyACM0 screen_wake
*/

#include <HID-Project.h>
#include <Wire.h>

#include "controls.h"
#include "led_state.h"
#include "trackball.h"

static const uint8_t PIN_BUTTON = 5;
static const uint8_t PIN_LED    = 9;  // must stay on a PWM pin
static const uint8_t PIN_ENC_A  = 7;  // INT6, if polling ever proves too slow
static const uint8_t PIN_ENC_B  = 8;  // PCINT4, likewise
static const uint8_t PIN_ENC_SW = 4;

static const uint16_t KEY_HOLD_MS = 60;  // far below Android's 500 ms long-press
static const uint16_t RESUME_MS   = 50;  // settling time after a remote wakeup

// Some OEM skins drop the OTG link after roughly ten minutes without traffic
// (measured on MIUI). An
// all-zero HID report presses nothing and keeps the bus from going idle. The
// app's own chatter covers this too, but only while the app is alive.
static const uint32_t KEEPALIVE_MS = 300000UL;

static Debounce wakeButton;
static Debounce encoderButton;
static Encoder  encoder;

static uint32_t lastTrafficMs  = 0;
static uint32_t blackoutStart  = 0;
static bool     blackoutActive = false;

static char     rxLine[RX_BUF];
static uint8_t  rxLen        = 0;
static uint32_t lastReportMs = 0;
static bool     everHeard    = false;
static bool     screenOn     = false;
static bool     batteryLow   = false;
static uint8_t  batteryPct   = 0;

static bool     trackballPresent = false;
static Rgbw     lastColour       = {0, 0, 0, 0};
static uint32_t lastTrackballMs  = 0;
static ClickDetector ballClick;

// Held briefly so the host sees a deliberate tap rather than a glitch, but far
// short of Android's long-press threshold.
static void sendKey(ConsumerKeycode key) {
  // A suspended bus swallows reports. Reopen the link first, then send the key.
  if (USBDevice.isSuspended()) {
    USBDevice.wakeupHost();
    delay(RESUME_MS);
  }
  Consumer.press(key);
  delay(KEY_HOLD_MS);
  Consumer.release(key);
}

// Volume steps arrive as fast as the knob turns, so they skip the hold above:
// 60 ms of delay per detent would cap a turn at sixteen steps a second and,
// worse, the loop would sit in delay() missing encoder transitions.
static void sendVolumeStep(bool up) {
  Consumer.write(up ? MEDIA_VOLUME_UP : MEDIA_VOLUME_DOWN);
}

static void confirmWithBlackout() {
  blackoutStart = millis();  // sendKey() blocks, so re-read the clock
  blackoutActive = true;
  lastTrafficMs = blackoutStart;
}

static void pollButtons(uint32_t now) {
  if (debouncePressed(wakeButton, digitalRead(PIN_BUTTON), now)) {
    sendKey(CONSUMER_POWER);
    confirmWithBlackout();
  }
  if (debouncePressed(encoderButton, digitalRead(PIN_ENC_SW), now)) {
    sendKey(MEDIA_VOLUME_MUTE);
    confirmWithBlackout();
  }
}

// No blackout on a volume step: a fast turn would strobe the LED, and the
// confirmation means "a key went out", not "every key went out".
static void pollEncoder() {
  const int8_t detents =
      encoderFeed(encoder, digitalRead(PIN_ENC_A), digitalRead(PIN_ENC_B));
  if (detents > 0) {
    sendVolumeStep(true);
  } else if (detents < 0) {
    sendVolumeStep(false);
  }
}

static void pollSerial(uint32_t now) {
  while (Serial.available()) {
    const char c = Serial.read();
    if (c == '\n' || c == '\r') {
      if (rxLen) {
        rxLine[rxLen] = '\0';
        const Report r = parseReport(rxLine);
        if (r.valid) {
          screenOn     = r.screenOn;
          batteryLow   = updateBatteryLow(batteryLow, r.battery);
          batteryPct   = r.battery;
          lastReportMs = now;
          everHeard    = true;
        }
        rxLen = 0;
      }
      continue;
    }
    // Drop the overflow rather than wrap: a truncated line fails to parse,
    // which is the outcome we want for anything this long.
    if (rxLen < RX_BUF - 1) {
      rxLine[rxLen++] = c;
    }
  }
}

static void serviceKeepalive(uint32_t now) {
  if (now - lastTrafficMs < KEEPALIVE_MS) {
    return;
  }
  lastTrafficMs = now;

  // Nothing to keep alive on a suspended or absent link. Resuming it here
  // would light the phone up unprompted, which is the opposite of the point.
  if (!USBDevice.configured() || USBDevice.isSuspended()) {
    return;
  }
  Consumer.releaseAll();
}

// Reading the chip ID is the presence test. Everything trackball-related is
// skipped when it fails, so the rig works unchanged with no module attached --
// which is how it ships today.
static bool trackballProbe() {
  Wire.beginTransmission(TRACKBALL_ADDR);
  Wire.write(REG_CHIP_ID_L);
  if (Wire.endTransmission() != 0) {
    return false;
  }
  if (Wire.requestFrom((uint8_t)TRACKBALL_ADDR, (uint8_t)2) != 2) {
    return false;
  }
  const uint8_t lo = (uint8_t)Wire.read();
  const uint8_t hi = (uint8_t)Wire.read();
  return (uint16_t)(((uint16_t)hi << 8) | lo) == TRACKBALL_CHIP_ID;
}

// Written only when the colour actually changes: the gradient moves with the
// battery, which is to say almost never, and an I2C write every loop pass
// would saturate the bus for nothing.
static void writeTrackballLed(const Rgbw& c) {
  if (c.r == lastColour.r && c.g == lastColour.g &&
      c.b == lastColour.b && c.w == lastColour.w) {
    return;
  }
  Wire.beginTransmission(TRACKBALL_ADDR);
  Wire.write(REG_LED_RED);
  Wire.write(c.r);
  Wire.write(c.g);
  Wire.write(c.b);
  Wire.write(c.w);
  if (Wire.endTransmission() == 0) {
    lastColour = c;
  }
}

// No blackout on the button LED for any of these: clicking is frequent while
// pointing, and the confirmation would become a strobe rather than a signal.
static void applyClickAction(ClickAction action) {
  switch (action) {
    case CLICK_LEFT:
      Mouse.click(MOUSE_LEFT);
      break;
    case CLICK_RIGHT:
      Mouse.click(MOUSE_RIGHT);
      break;
    case DRAG_START:
      Mouse.press(MOUSE_LEFT);
      break;
    case DRAG_END:
      Mouse.release(MOUSE_LEFT);
      break;
    case CLICK_NONE:
      break;
  }
}

static void pollTrackball(uint32_t now) {
  if (!trackballPresent) {
    return;
  }
  if (now - lastTrackballMs < TRACKBALL_POLL_MS) {
    return;  // see TRACKBALL_POLL_MS: this read would otherwise starve the encoder
  }
  lastTrackballMs = now;

  // Aborting on a failed read is not tidiness: losing the module mid-drag
  // would otherwise leave the left button held down for good.
  Wire.beginTransmission(TRACKBALL_ADDR);
  Wire.write(REG_LEFT);
  if (Wire.endTransmission() != 0) {
    applyClickAction(clickAbort(ballClick));
    return;
  }
  if (Wire.requestFrom((uint8_t)TRACKBALL_ADDR, (uint8_t)5) != 5) {
    applyClickAction(clickAbort(ballClick));
    return;  // a module that went quiet must not move the pointer at random
  }

  uint8_t raw[5];
  for (uint8_t i = 0; i < 5; i++) {
    raw[i] = (uint8_t)Wire.read();
  }
  const BallFrame f = decodeFrame(raw);

  // Settle the gesture before the movement goes out, so a drag grabs from
  // where the button went down rather than a few counts further along.
  applyClickAction(clickFeed(ballClick, f.held, f.dx, f.dy, now));

  const int8_t mx = pointerStep(f.dx);
  const int8_t my = pointerStep(f.dy);
  if (mx != 0 || my != 0) {
    Mouse.move(mx, my);  // silence when still, or the bus floods at loop rate
  }
}

static void updateTrackballLed(bool usbConfigured, bool appAlive) {
  if (!trackballPresent) {
    return;
  }
  writeTrackballLed(batteryColour(batteryPct, usbConfigured && appAlive, screenOn));
}

static void updateLed(uint32_t now) {
  if (blackoutActive && now - blackoutStart >= BLACKOUT_MS) {
    blackoutActive = false;
  }

  LedInputs in;
  in.usbConfigured = USBDevice.configured();
  in.appAlive      = everHeard && (now - lastReportMs < APP_TIMEOUT_MS);
  in.screenOn      = screenOn;
  in.batteryLow    = batteryLow;
  in.blackout      = blackoutActive;
  in.nowMs         = now;

  updateTrackballLed(in.usbConfigured, in.appAlive);
  analogWrite(PIN_LED, ledLevel(in));
}

// The core hangs the TX and RX LEDs off the USB interrupt and pulses them on
// every packet. With the app reporting several times a second that is a
// constant flicker, and this rig lives behind a phone rather than on a bench.
//
// Both sit on pins no header exposes, so pinMode() cannot reach them. Only the
// direction register matters: the core keeps writing the port bits from its
// interrupt handler and an input pin ignores them. It arms these two as
// outputs in USBDevice.attach(), which the core runs before setup(), and never
// again -- so undoing it here holds.
//
// PB0 doubles as the SPI slave-select line. Nothing here uses SPI; a future
// device on that bus would have to take the pin back.
static void silenceUsbLeds() {
  DDRD &= (uint8_t)~(1 << 5);  // TX
  DDRB &= (uint8_t)~(1 << 0);  // RX
}

void setup() {
  pinMode(PIN_BUTTON, INPUT_PULLUP);
  pinMode(PIN_ENC_SW, INPUT_PULLUP);
  pinMode(PIN_ENC_A, INPUT_PULLUP);
  pinMode(PIN_ENC_B, INPUT_PULLUP);
  pinMode(PIN_LED, OUTPUT);
  Serial.begin(115200);
  silenceUsbLeds();
  Consumer.begin();
  Mouse.begin();
  Wire.begin();  // default 100 kHz; the module is rated for 250 kHz at most
  trackballPresent = trackballProbe();

  // Seed from the pins as they actually are. Assuming a resting state would
  // make the first poll look like movement and nudge the volume at power-up.
  const uint32_t now = millis();
  wakeButton = debounceInit(digitalRead(PIN_BUTTON), now);
  encoderButton = debounceInit(digitalRead(PIN_ENC_SW), now);
  encoder = encoderInit(digitalRead(PIN_ENC_A), digitalRead(PIN_ENC_B));
  ballClick = clickInit();
  lastTrafficMs = now;
}

void loop() {
  // Each stage reads the clock itself. pollButtons() blocks while it sends a
  // key, so a timestamp captured once up here would reach updateLed() older
  // than the blackout it is meant to time -- and the unsigned subtraction
  // would wrap rather than go negative, cancelling the blackout outright.
  //
  // The encoder is sampled first because it is the only input with no state
  // machine of its own to survive a missed sample: a dropped transition is a
  // lost detent, where a dropped button sample is simply read again next pass.
  pollEncoder();
  pollTrackball(millis());
  pollButtons(millis());
  pollSerial(millis());
  serviceKeepalive(millis());
  updateLed(millis());
}

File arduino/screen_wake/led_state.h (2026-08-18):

/*
  Pure decision logic for the button LED. No Arduino API, no pin access, no
  USB: everything here is a function of integers and time, which is what makes
  it testable on the host with plain g++.
*/
#pragma once

#include <stdint.h>

static const uint8_t  LED_AWAKE     = 24;
static const uint8_t  BREATHE_FLOOR = 2;
static const uint8_t  BREATHE_CEIL  = LED_AWAKE;
static const uint16_t BREATHE_MS    = 4000;
static const uint16_t BLINK_MS      = 125;
static const uint16_t BLACKOUT_MS   = 120;

static const uint8_t  BATT_FLASH_LEVEL   = 200;
static const uint16_t BATT_FLASH_MS      = 60;
static const uint16_t BATT_FLASH_GAP_MS  = 120;
static const uint16_t BATT_PERIOD_MS     = 5000;
static const uint8_t  BATT_LOW_PCT       = 15;
static const uint8_t  BATT_CLEAR_PCT     = 20;

static const uint32_t APP_TIMEOUT_MS = 15000;
static const uint8_t  RX_BUF         = 32;

// Triangle ramp, squared. The eye responds to light logarithmically, so a
// linear ramp reads as a hard stop at each end rather than a breath.
inline uint8_t breatheLevel(uint32_t nowMs) {
  const uint16_t half  = BREATHE_MS / 2;
  const uint16_t phase = nowMs % BREATHE_MS;
  const uint8_t  tri   = (phase < half) ? (phase * 255UL / half)
                                        : ((BREATHE_MS - phase) * 255UL / half);
  const uint8_t  curve = (uint16_t)tri * tri >> 8;
  return BREATHE_FLOOR + ((uint16_t)curve * (BREATHE_CEIL - BREATHE_FLOOR) >> 8);
}

// Hard 4 Hz square wave. Fast and abrupt reads as a fault, where the slow
// smooth breath reads as normal.
inline uint8_t blinkLevel(uint32_t nowMs) {
  return ((nowMs / BLINK_MS) % 2) ? 0 : LED_AWAKE;
}

struct Report {
  bool    valid;
  bool    screenOn;
  uint8_t battery;
};

// Parses one complete line, "S<0|1> B<0..100>". Anything else yields
// valid=false: a garbled line must never be mistaken for fresh news.
inline Report parseReport(const char* line) {
  Report r = {false, false, 0};

  if (line[0] != 'S') {
    return r;
  }
  if (line[1] != '0' && line[1] != '1') {
    return r;
  }
  if (line[2] != ' ' || line[3] != 'B') {
    return r;
  }

  uint16_t value  = 0;
  uint8_t  digits = 0;
  for (uint8_t i = 4; line[i] != '\0'; i++) {
    if (line[i] < '0' || line[i] > '9') {
      return r;
    }
    value = value * 10 + (line[i] - '0');
    if (++digits > 3) {
      return r;
    }
  }
  if (digits == 0 || value > 100) {
    return r;
  }

  r.valid    = true;
  r.screenOn = (line[1] == '1');
  r.battery  = (uint8_t)value;
  return r;
}

// Hysteresis. Without the dead band between the two thresholds, a charge
// sitting on the line would toggle the alert endlessly.
inline bool updateBatteryLow(bool current, uint8_t battery) {
  if (battery < BATT_LOW_PCT) {
    return true;
  }
  if (battery > BATT_CLEAR_PCT) {
    return false;
  }
  return current;
}

// Two brief pulses per period. Returns 0 outside the pulses, so the caller
// can fall through to whatever the base state wanted to show.
inline uint8_t battFlashLevel(uint32_t nowMs) {
  const uint16_t t = nowMs % BATT_PERIOD_MS;
  if (t < BATT_FLASH_MS) {
    return BATT_FLASH_LEVEL;
  }
  const uint16_t second = BATT_FLASH_MS + BATT_FLASH_GAP_MS;
  if (t >= second && t < second + BATT_FLASH_MS) {
    return BATT_FLASH_LEVEL;
  }
  return 0;
}

struct LedInputs {
  bool     usbConfigured;
  bool     appAlive;
  bool     screenOn;
  bool     batteryLow;
  bool     blackout;
  uint32_t nowMs;
};

// The order below is a priority list, not a style choice. Press confirmation
// must be visible whatever else is happening; a dead link outranks any claim
// about the phone; a silent app outranks a screen state we can no longer
// vouch for, which is also why the battery alert is suppressed there.
inline uint8_t ledLevel(const LedInputs& in) {
  if (in.blackout) {
    return 0;
  }
  if (!in.usbConfigured) {
    return 0;
  }
  if (!in.appAlive) {
    return blinkLevel(in.nowMs);
  }
  if (in.batteryLow) {
    const uint8_t flash = battFlashLevel(in.nowMs);
    if (flash) {
      return flash;
    }
  }
  return in.screenOn ? LED_AWAKE : breatheLevel(in.nowMs);
}

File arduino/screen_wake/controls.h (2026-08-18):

/*
  Pure decision logic for the physical controls: turning raw pin samples into
  discrete input events. No Arduino API, no pin access, no USB -- everything
  here is a function of booleans, integers and time, which is what makes it
  testable on the host with plain g++.

  Two primitives live here because both buttons on this rig need the same
  debounce, and duplicating that block was the alternative.
*/
#pragma once

#include <stdint.h>

// Every button on this rig is wired to ground and read with the internal
// pull-up, so a press reads LOW.
static const uint32_t DEBOUNCE_MS = 30;

// An EC11 usually emits four quadrature transitions between detents; some
// emit two. If one click of the knob moves the volume by more than one step,
// this is the number to change.
static const int8_t STEPS_PER_DETENT = 4;

// ---------------------------------------------------------------- debounce

struct Debounce {
  bool     stable;      // the level we have accepted as settled
  bool     lastRead;    // the level of the previous sample
  uint32_t lastEdgeMs;  // when the raw sample last changed
};

inline Debounce debounceInit(bool high, uint32_t nowMs) {
  Debounce d;
  d.stable = high;
  d.lastRead = high;
  d.lastEdgeMs = nowMs;
  return d;
}

// Feed one raw sample. Returns true exactly once per press, at the moment the
// low level has held still for DEBOUNCE_MS. Releases return false: callers
// want the press edge, and reporting both would make every caller filter.
inline bool debouncePressed(Debounce& d, bool high, uint32_t nowMs) {
  if (high != d.lastRead) {
    d.lastRead = high;
    d.lastEdgeMs = nowMs;
    return false;
  }
  if (high == d.stable || nowMs - d.lastEdgeMs < DEBOUNCE_MS) {
    return false;
  }
  d.stable = high;
  return !high;
}

// --------------------------------------------------------------- quadrature

struct Encoder {
  uint8_t prevState;    // last AB pair, 0..3
  int8_t  accumulated;  // transitions banked since the last whole detent
};

inline Encoder encoderInit(bool a, bool b) {
  Encoder e;
  e.prevState = (uint8_t)((a ? 2 : 0) | (b ? 1 : 0));
  e.accumulated = 0;
  return e;
}

// Indexed by (previous AB << 2) | current AB. The zeros on the diagonal are
// samples where nothing moved; the zeros where both bits flip are transitions
// a real encoder cannot make, so they are noise and are dropped rather than
// counted in whichever direction the arithmetic happened to favour.
static const int8_t QUADRATURE[16] = {
   0, -1,  1,  0,
   1,  0,  0, -1,
  -1,  0,  0,  1,
   0,  1, -1,  0
};

// Feed one sampled pin pair. Returns -1, 0 or +1 whole detents. Sub-detent
// movement is banked, so nudging the knob without reaching a click -- or
// reaching one and coming back -- changes nothing.
inline int8_t encoderFeed(Encoder& e, bool a, bool b) {
  const uint8_t curr = (uint8_t)((a ? 2 : 0) | (b ? 1 : 0));
  const int8_t step = QUADRATURE[(e.prevState << 2) | curr];
  e.prevState = curr;

  if (step == 0) {
    return 0;
  }
  e.accumulated = (int8_t)(e.accumulated + step);

  if (e.accumulated >= STEPS_PER_DETENT) {
    e.accumulated = (int8_t)(e.accumulated - STEPS_PER_DETENT);
    return 1;
  }
  if (e.accumulated <= -STEPS_PER_DETENT) {
    e.accumulated = (int8_t)(e.accumulated + STEPS_PER_DETENT);
    return -1;
  }
  return 0;
}

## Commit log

2026-08-14 feat(android): report screen state and battery over USB serial
2026-08-18 feat(arduino): screen wake button, trackball and rotary encoder
2026-08-24 feat(pcb): cipher2-panel, the hub board the deck's controls plug into
    A 100 x 42 mm two-layer board carrying a Pro Micro on sockets and four
    connectors. The button, the encoder and the trackball are mounted in the
    enclosure and reach it on cable, so the board only wires them together --
    the firmware's pinout is unchanged.
    Generated, not drawn. tools/netlist.py is the single place a connection is
    written down; the schematic and the board are both produced from it, so two
    generators cannot drift from one source. The .kicad_pcb is an output and is
    never edited by hand.
    Verified end to end. A test reads screen_wake.ino itself and asserts the
    board follows the sketch's PIN_* constants rather th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
    [bom-full.csv, bom.csv, cipher2-panel-Edge_Cuts.dxf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]
2026-09-01 docs(pcb): record the mating hardware the BOM cannot carry
    The sockets and the module's pin headers accouple U1; they are not
    components of the schematic, and fab/bom.csv is generated from that
    schematic. They could never appear there -- and that silence is what let a
    tulip strip get bought and soldered, which a square 0.64 mm pin cannot
    enter: 0.90 mm across the diagonal against a contact bored for 0.8 mm
    round leads.
    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
2026-09-16 fix(arduino): match the pointer axes to the trackball mounting
    [trackball.h]
